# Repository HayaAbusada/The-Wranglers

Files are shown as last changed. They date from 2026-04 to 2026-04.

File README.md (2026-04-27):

# The-Wranglers
Final Deliverables Repository containing all materials used to develop this project.

## CSCE 483: Student Pick Up System Contents

### Designs: code, schematics, data, data sheets, freeware software tools, etc.
- Low Fidelity Designs
- CAD Designs
- Camera Code
- Website Code
- Server Code
- Raspberry Pi Data Sheet
- Raspberry Pi Camera Data Sheet

### Reports: proposal, CDR, weekly reports, final report, and ALL presentations
- Proposal
- CDR
- Final Report
- Weekly Report #1
- Weekly Report #2
- Weekly Report #3
- Weekly Report #4
- Weekly Report #5
- Weekly Report #6
- Weekly Report #7
- Proposal Presentation
- CDR Presentation
- Final Presentation

### Audiovisual Media: close-up pictures and demo video
- Video Demo
- System Photos

### Individual Notebooks (Digital)
- Jack Uehlinger’s Notebook
- Jake Hewett’s Notebook
- Jayden Pearson’s Notebook
- Sara Vorhaben’s Notebook 
- Haya Abusada’s Notebook

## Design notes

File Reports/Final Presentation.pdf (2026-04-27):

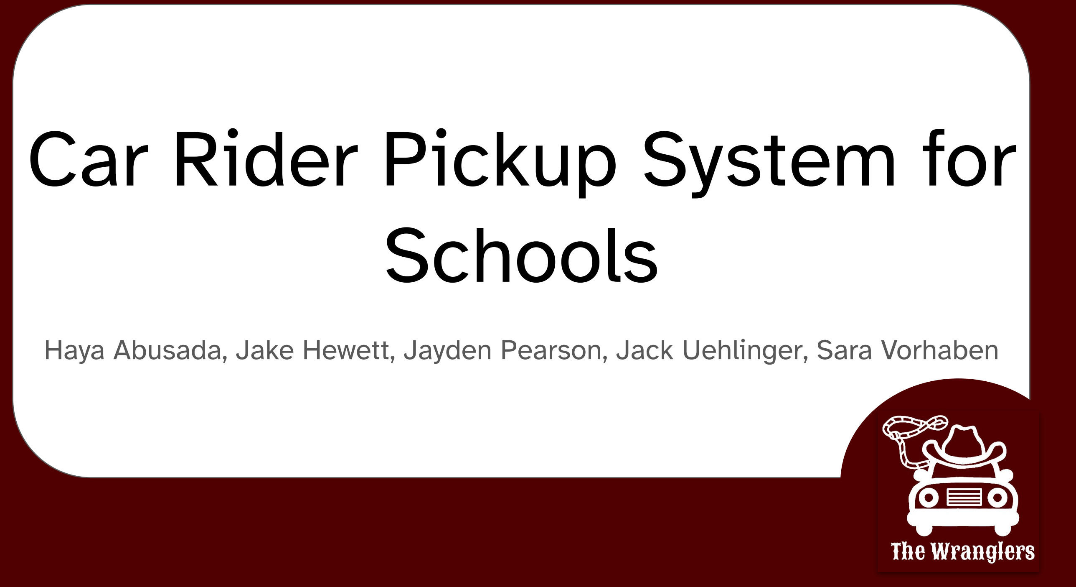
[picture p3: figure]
Car Rider Pickup System for Schools

# Haya Abusada, Jake Hewett, Jayden Pearson, Jack Uehlinger, Sara Vorhaben

# Problem Background

- Over 70% of students are now picked up via car, creating massive congestion.
- Parents wait up to 1 hour, with lines often forming 1-2 hours before dismissal.
- Queues spill onto local highways, causing traffic backups and increasing accident risks.
- Inclement weather increases delays as bus and bike riders often switch to the car line.

## - The manual process requires 5-10 staff members daily, diverting them from educational

duties.

# Problem - Needs Statement

## School pickup via the car rider line has been increasing in the US over the years leading to an increase in line length and pickup time. Now, over 70% of students are

picked up from school via the car rider line. Car rider lines have become congested,

posing a safety issue for both the students and other drivers. With more students attending school, car rider lines have become too slow and cause parents to wait up to over an hour in line leading to frustration. Some studies show that the car rider pick-up line starts to form 1-2 hours before school actually gets out, which leads to traffic backing up local highways and streets, and even frequent accidents. Inclement weather further slows the line, as students who ride the bus or bike to school will often

be picked up by their parents in the car rider line to avoid the weather. Additionally, 5-10

## staff members are required to set up and run the pickup process, diverting their time away from the education of students. An automated system is needed to streamline the

pick-up process to decrease delays and safety issues.

# Goal and Objectives

## Goal

The goal of this project is to design and prototype a system that will help automate the car rider pick up process at schools. The system is built to reduce the amount of time necessary to pick up students from school.

## Objectives

- The system will allow parents to update their information (license plate numbers, approved adults for pickup, car rider schedules) via a website with approval from a staff member of the school.
- The system will read the marker on the car (license plate, QR code, nametag) as it enters the pickup line and send the information to a server.
- The server will identify the parent and child associated with the car marker, and update a display at the entrance of the pickup line to direct the car to the proper station.
- The laptop at the front of the school is updated to inform the students and staff which child is being picked up, and which zone to go to.

# Goal and Objectives - Requirements

# Marketing Requirements

1. Make the pickup process faster for parents 2. The system should be easily updated 3. The system should be low cost 4. The system should be easy to use/install 5. Information must be validated if updated or inserted 6. Student safety should be ensured (information, physical, etc.) 7. The system should be reliable

# Goal and Objectives - Requirements

Marketing Requirements | Engineering Requirements | How Requirement was met
1 | Pickup time should be reduced by 30% per 100 kids. The time from the car entering the view of the camera to information being displayed should be no more than 5 seconds. | display updates <1 second
4 | 7 inch (diagonal) display screen to give station and process instructions clearly. | See Setup
1, 6 | Per Texas Family Code, ensure that students are referred to authorized parents 100% of the time. | Scanned QR code only works for approved users
6 | Private Information stored in the database should be encrypted using 128 bit encryption. | Database automatically encrypts
1,6,7 | Should correctly identify/assign parents to kids 100% of the time. | See Full System Test
3 | The costs for developing the system should not exceed $300. | See Budget
2,4,5 | The system should allow parents to submit a request to the school to update information and the school should receive the request all within 1 minute. | Aproval requests can be seen in system in <1 second

# Goal and Objectives - Requirements

Marketing Requirements | Engineering Requirements | How Requirement was met
4 | The system should have a modular design such that failed components can be replaced by a technician in under 15 minutes. | System designed so each system component could easily be replaced if broken
7 | The software will comply with the Digital Millennium Copyright Act. | No code was copied from existing sites
2,4,5,6 | Staff should be able to access databases with provided credentials and view all parent to children links. | See staff portal
1 | Minimum 40inch (diagonal) display screen to give station and process instructions clearly inside in the pickup . | See System Setup: display Student Pickup screen inside on TV/Smartboard in classroom
4,7 | The system should be mounted correctly on a tripod to ensure stability and prevent hazards. | See Car Entrance Model Setup.

# Design Constraints and Feasibility

Technical and Temporal Constraints

- Maximum of 5 seconds from image capture to display update
- Identification accuracy must be 100% to ensure safety and efficiency
- Connection between the system parts must be reliable

Physical and Environmental

- Needs to withstand outdoor elements (wind and rain)
- Needs to be portable and stable with modular parts, mounting, and power supply to reduce system downtime and speed up repair and maintenance

Economic

- Must cost $250 or less, necessitating cost-effective components

Feasibility

- Core technology, such as Python image processing and Wi-Fi, is well documented and achievable
- Main challenge will be creating a fast and efficient system within our budget

# Design Alternatives and Rationale

Solution | Pros | Cons
Manual Pickup App (PikMyKid) | Easy to implement; low cost; reduces paperwork | Requires staff queue management; no automated vehicle identification
Integrated Dismissal System (Beeline) | Improves communication; integrates with school systems | Requires training and infrastructure; still staff-monitored
Geofencing (Car-Pool App) | Real-time arrival alerts; reduced manual check-ins | Dependent on GPS accuracy, mobile devices, and connectivity
GPS Check-In (IschoolRide) | Keeps students inside until arrival; reduces idle staging | Relies on parent app usage and accurate GPS; staff verification will still be needed

All alternatives improve organization but still rely on staff actions, limiting full automation.

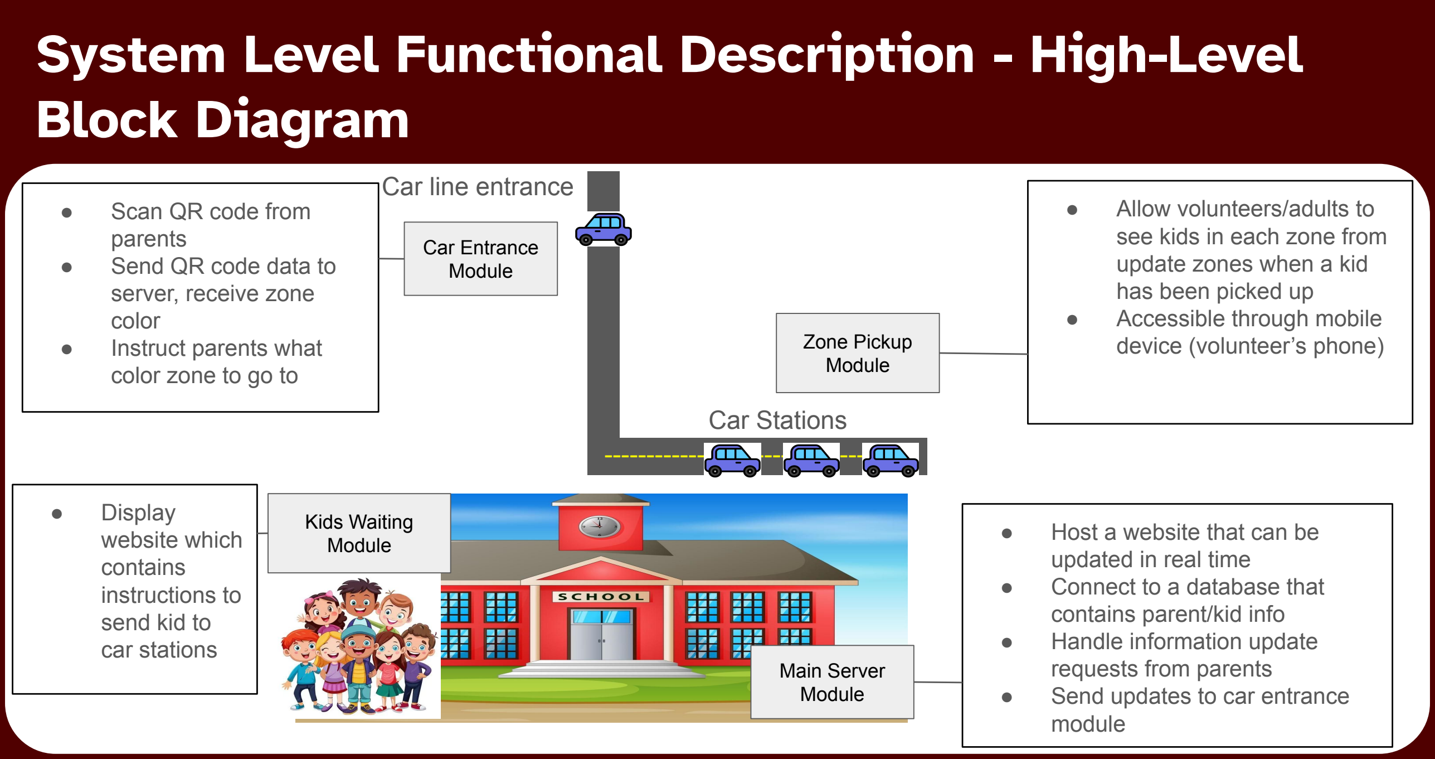
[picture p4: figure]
Block Diagram; Car line entrance; Car Stations; Car Entrance Module; Main Server Module; Kids Waiting Module; Zone Pickup Module; ● Scan QR code from parents ● Send QR code data to server, receive zone color ● Instruct parents what color zone to go to; ● Display website which contains instructions to send kid to car stations; ● Allow volunteers/adults to see kids in each zone from update zones when a kid has been picked up ● Accessible through mobile device (volunteer’s phone)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

# System Level Functional Description - High-Level

# System Component - Car Entrance Module

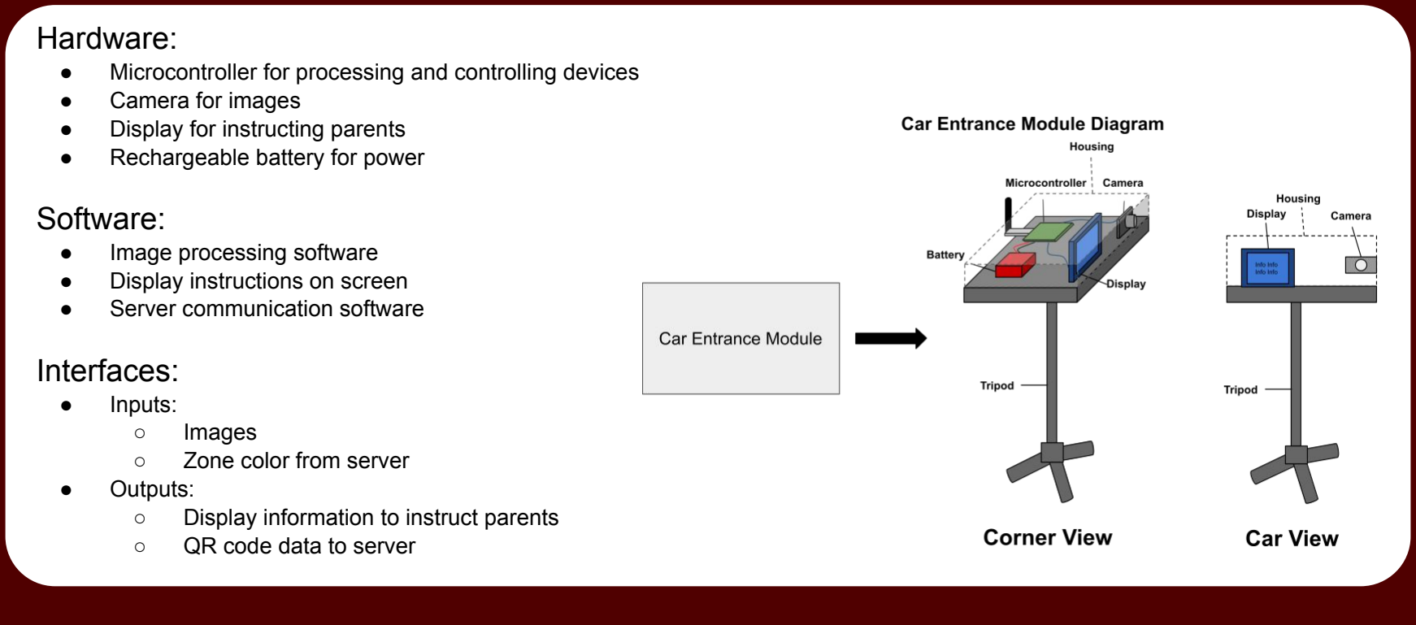
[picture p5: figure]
Hardware:; ● Camera for images ● Display for instructing parents ● Rechargeable battery for power; Software:; ● Image processing software ● Display instructions on screen ● Server communication software; Interfaces:; ● Inputs: ○ Images ○ Zone color from server ● Outputs:; ○ QR code data to server

- Microcontroller for processing and controlling devices
- Display information to instruct parents

System Component - Car Entrance Module cont.

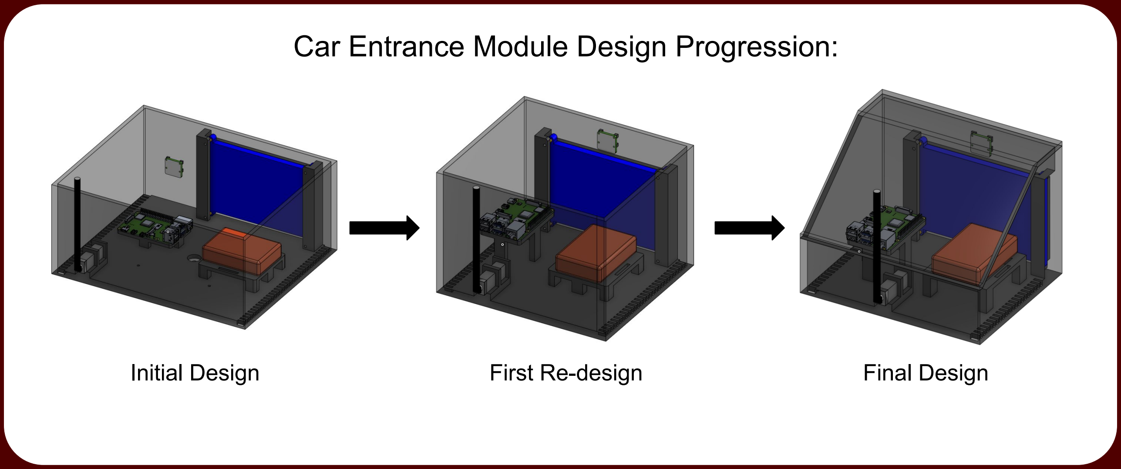
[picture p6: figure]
Car Entrance Module Design Progression:

Initial Design | First Re-design | Final Design

# System Component - Zone Pickup Module

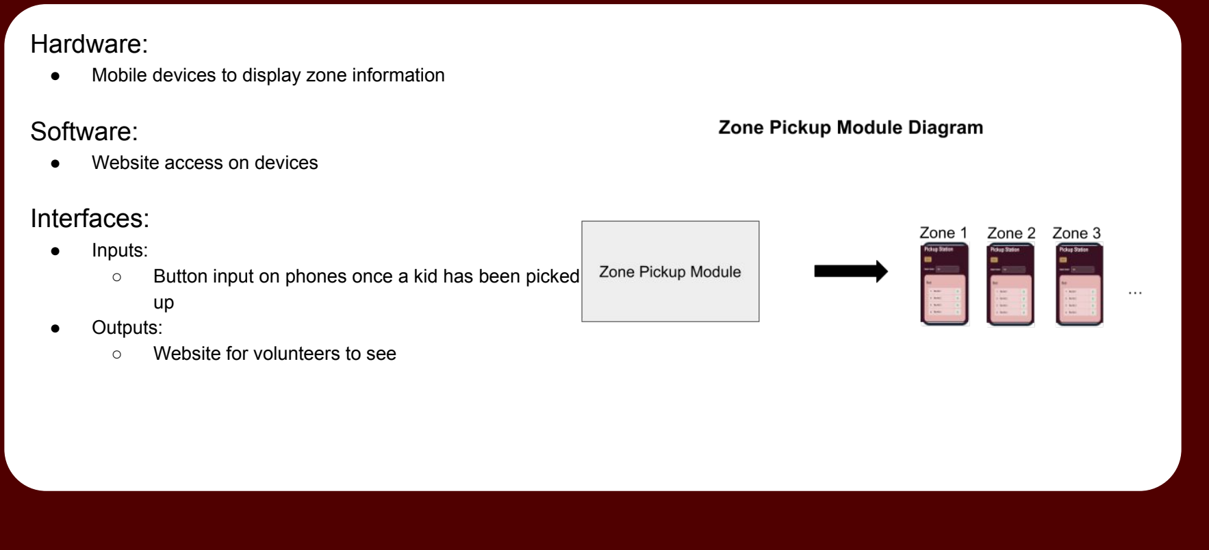
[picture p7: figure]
Hardware:; Software:; ● Website access on devices; Interfaces:; ● Inputs:; up ● Outputs: ○ Website for volunteers to see

- Mobile devices to display zone information
- Button input on phones once a kid has been picked

# System Component - Main Server Module

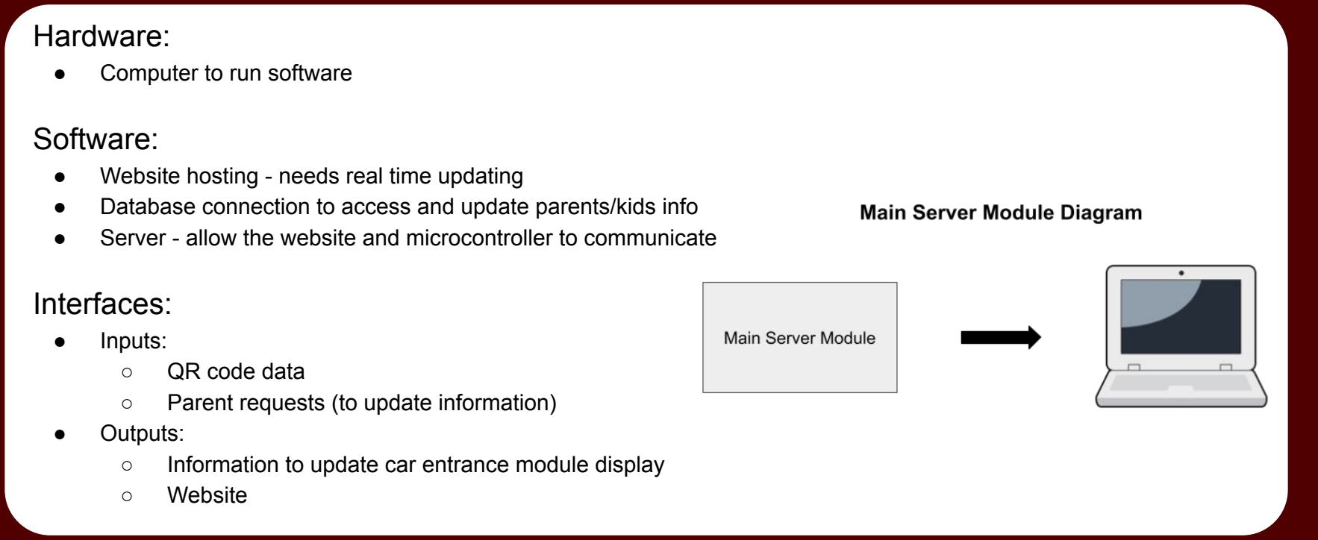
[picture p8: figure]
Hardware:; ● Computer to run software; Software:; Interfaces:; ● Inputs: ○ QR code data; ● Outputs:; ○ Website

- Website hosting - needs real time updating
- Database connection to access and update parents/kids info
- Server - allow the website and microcontroller to communicate
- Parent requests (to update information)
- Information to update car entrance module display

# System Component - Kids Waiting Module

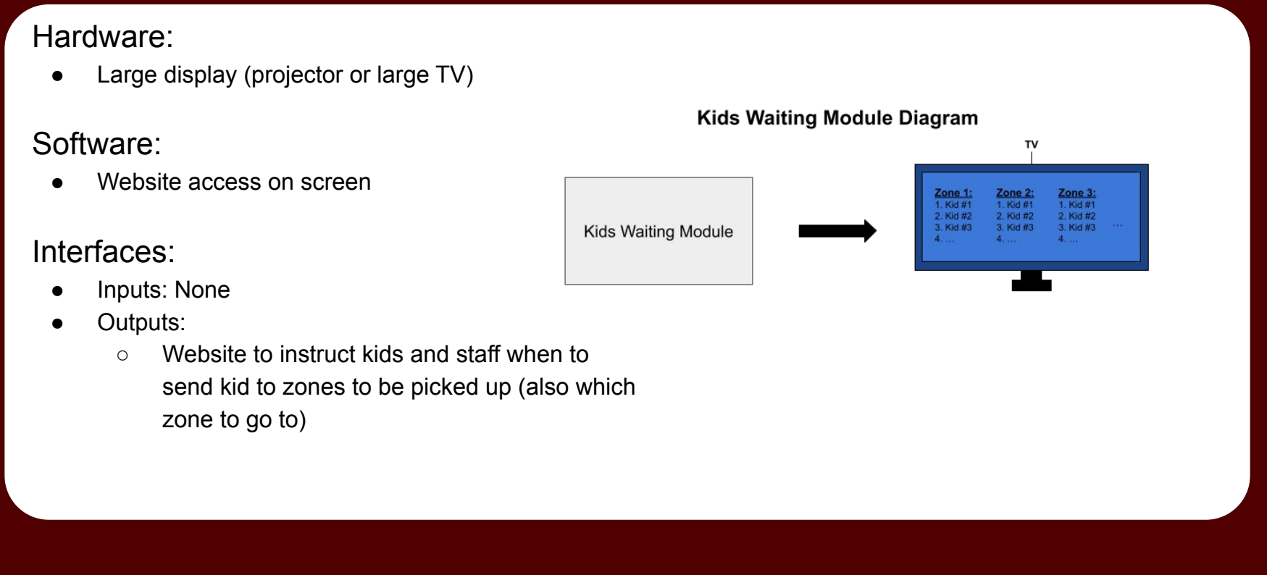
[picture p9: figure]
Hardware:; ● Large display (projector or large TV); Software:; ● Website access on screen; Interfaces:; ● Inputs: None ● Outputs:; zone to go to)

- Website to instruct kids and staff when to send kid to zones to be picked up (also which

# Budget Breakdown

Module | Component | Description | Qty | Unit Cost ($) | Total Cost ($)
Car Entrance | Tripod | Tripod to support car entrance module housing. | 1 | $22 | $22
Car Entrance | Raspberry Pi | Microcontrollers to control car entrance and zone pickup modules. | 1 | $75 | $75*
Car Entrance | Raspberry Pi Camera | Camera to use license plate recognition of cars. | 1 | $55 | $55*
Car Entrance | 10000mAh Rechargeable Battery | Batteries to give sufficient power to the car entrance and zone pickup module. | 1 | $40 | $40
Car Entrance | 7-inch display | Display to inform the parent of the car what zone to go to, and verify we have matched their car with their kid. | 1 | $38 | $38*
Car Entrance | HDMI Cord | HDMI cord to connect the microcontroller to the display. | 1 | $4 | $4
Car Entrance | 3D printing | 3D printed housings for car entrance and zone pickup modules. | | | $36.55**
Car Entrance | Mounting Screws | Screws to securely mount components to housings. | ~40 | $8 (600pcs) | $8
Total* (not including components provided) | | | | | $74
Total | | | | | $278.55

Budget Breakdown - cont.

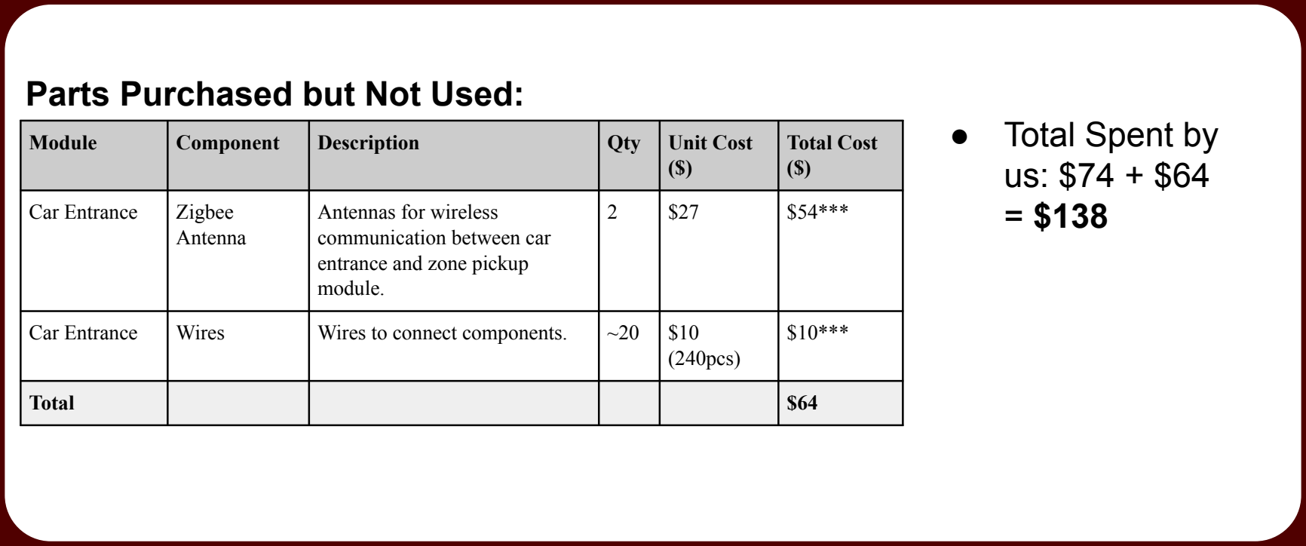
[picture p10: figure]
Module; Component; Description; Qty; Unit Cost ($); Total Cost ($); Car Entrance; Wires; Wires to connect components.; $10 (240pcs); Total; Parts Purchased but Not Used:; ● Total Spent by us: $74 + $64 = $138

Car Entrance | Zigbee Antenna | Antennas for wireless communication between car entrance and zone pickup module. | 2 | $27 | $54***

# Evidence of Effective Teaming

Defined Roles and Responsibilities

Each team member is responsible for a specific subsystem:

- Haya Abusada – Frontend development and system integration
- Sara Vorhaben – Backend development and authentication
- Jake Hewett – Database architecture and administrative interface
- Jack Uehlinger – Hardware and camera integration
- Jayden Pearson – Mechanical design and enclosure development

This ensures clear ownership of tasks and efficient development.

Collaboration and Communication

The team maintains strong coordination through:

- Weekly team meetings to review progress and address issues
- GitHub for version control and collaborative development
- Discord and Text for daily communication and troubleshooting
- Google Drive for shared documentation and reports

Screenshot of Github Repo

# Evidence of Effective Teaming - Gantt Chart

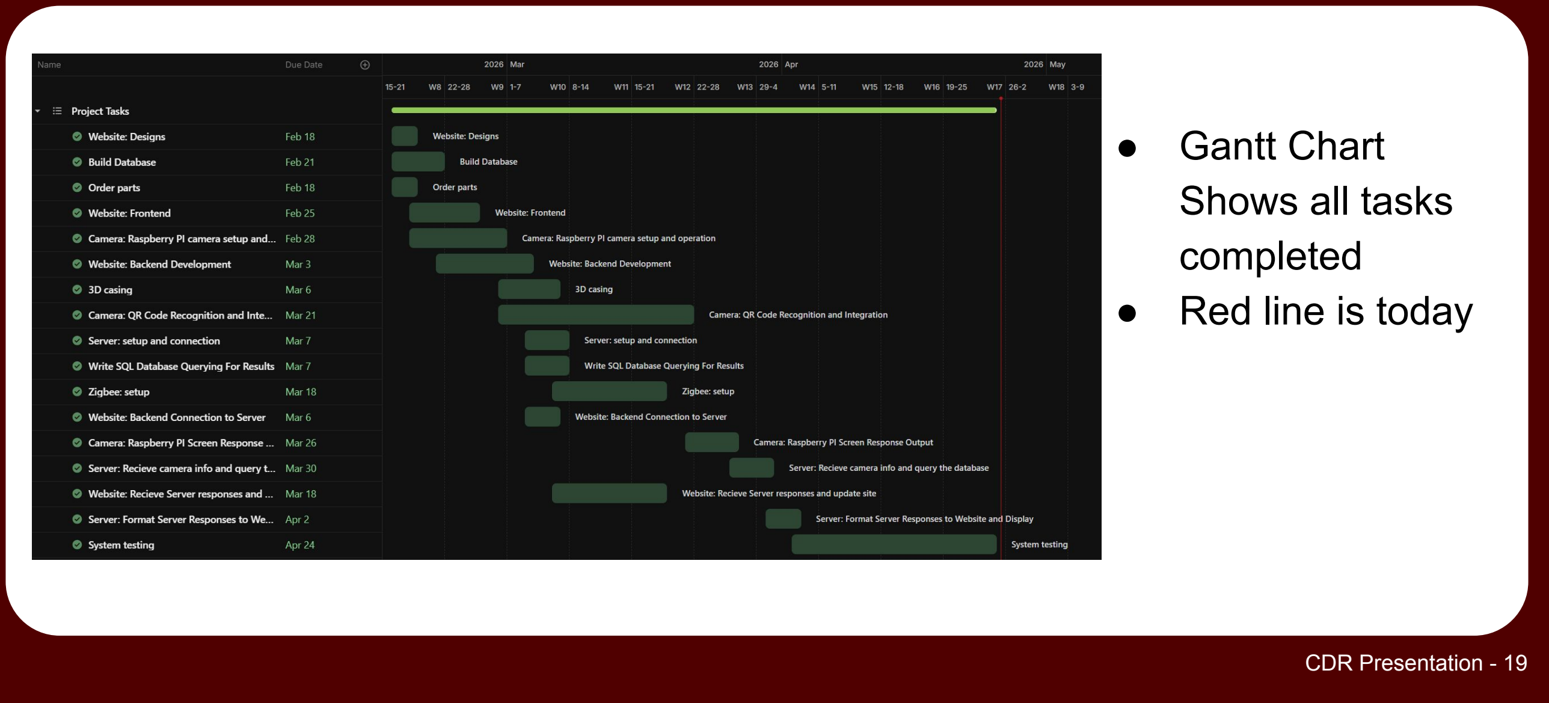
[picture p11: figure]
● Gantt Chart Shows all tasks completed ● Red line is today; CDR Presentation - 19

# Environmental, Health, and Safety Concerns

### Environmental Impact

### - Minimal hardware footprint (primarily existing devices like monitors and Raspberry Pi) - Reduced vehicle idling time → lowers emissions during pickup - Digital system reduces paper usage (no printed pickup lists)

### Health Considerations

### - Contactless QR code system reduces physical interaction - Minimizes crowding and improves traffic flow for safer pickup conditions

### Safety Considerations

### - Clear, color-coded display reduces confusion for drivers - Organized station system prevents congestion and accidents

# Social, Political, and Ethical Concerns

- Social Impact - Improves efficiency and reduces wait times for families - Enhances safety for students during pickup - Accessible interface designed for non-technical users - Ethical Considerations - Protection of personal data (student and parent information) - Use of secure authentication (Google OAuth) - Controlled access to staff-only features - Political / Regulatory Considerations - Must comply with school policies and student privacy regulations (e.g., FERPA) - Requires proper authorization for data collection and usage - Deployment depends on school/district approval and infrastructure

# Manufacturability, sustainability, and economics

### Manufacturability - Software-based system → easily deployable and scalable - Uses widely available hardware (monitors, laptops, Raspberry Pi) - No specialized manufacturing required

### Sustainability - Reduces fuel consumption through optimized pickup flow - Digital-first approach minimizes material waste - Scalable system reduces need for additional infrastructure

### Economic Considerations - Low implementation cost (open-source tools, cloud services) - Minimal hardware investment - Reduces labor inefficiencies and operational costs for schools

# Our Final Product Video

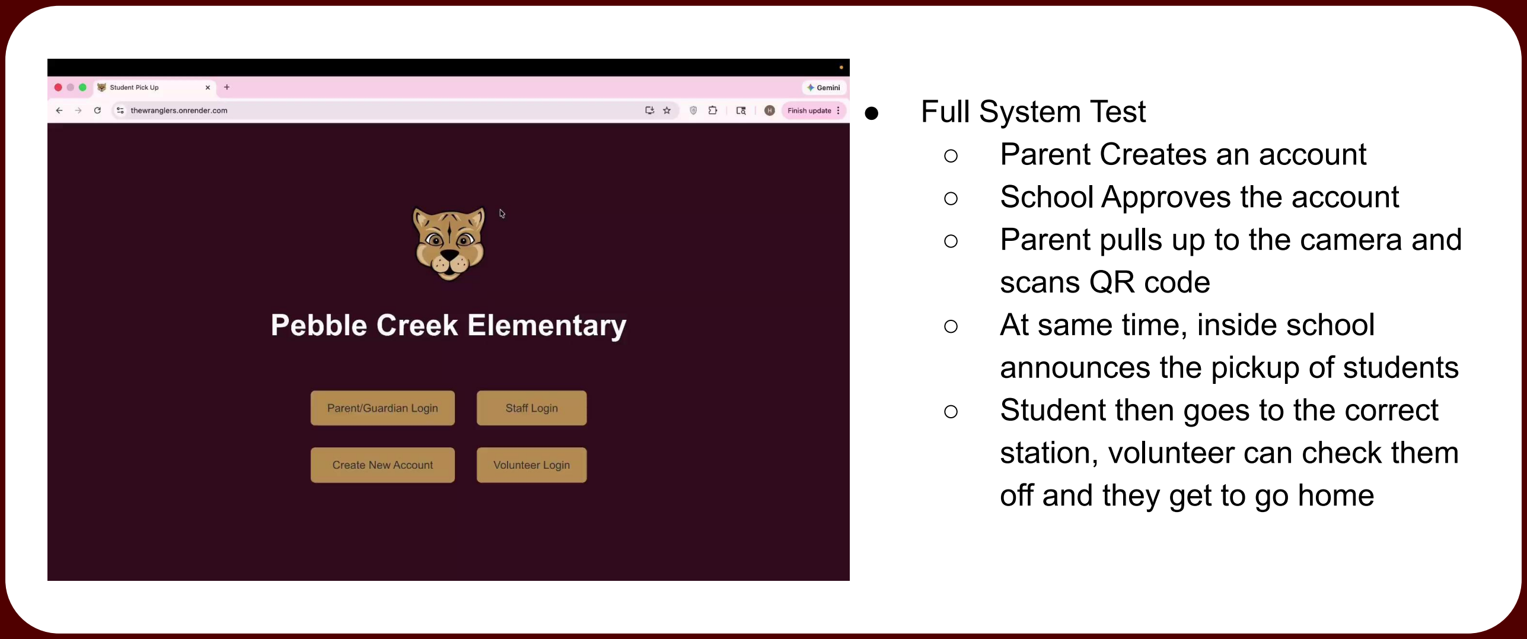
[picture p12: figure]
● Full System Test ○ Parent Creates an account ○ School Approves the account ○ Parent pulls up to the camera and scans QR code ○ At same time, inside school announces the pickup of students ○ Student then goes to the correct station, volunteer can check them off and they get to go home; video

# Testing and Results

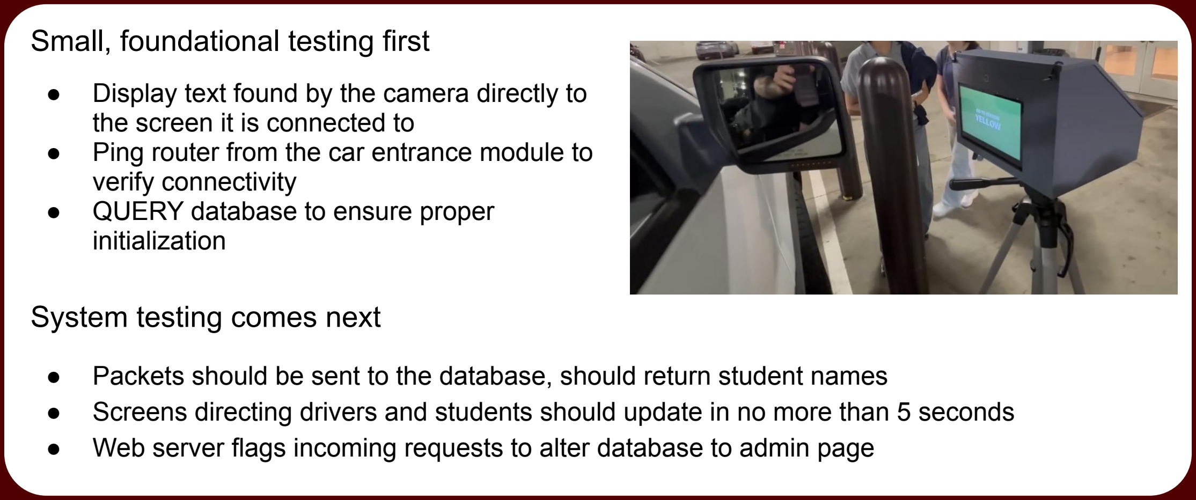
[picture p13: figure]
Small, foundational testing first; the screen it is connected to; verify connectivity ● QUERY database to ensure proper initialization; System testing comes next

## - Display text found by the camera directly to

## - Ping router from the car entrance module to

## - Packets should be sent to the database, should return student names - Screens directing drivers and students should update in no more than 5 seconds - Web server flags incoming requests to alter database to admin page

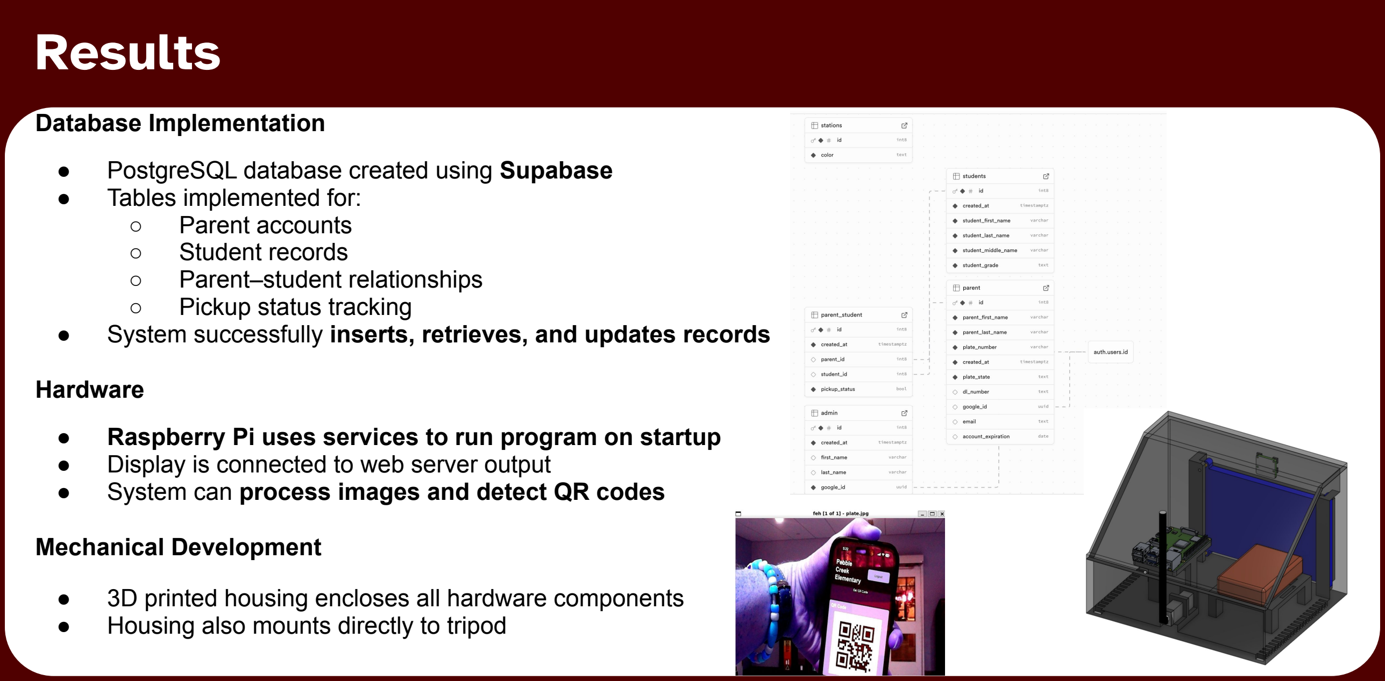
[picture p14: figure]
Results; Database Implementation; ● Tables implemented for: ○ Parent accounts ○ Student records ○ Parent–student relationships ○ Pickup status tracking; Hardware; Mechanical Development

- PostgreSQL database created using Supabase
- System successfully inserts, retrieves, and updates records
- Raspberry Pi uses services to run program on startup
- Display is connected to web server output
- System can process images and detect QR codes
- 3D printed housing encloses all hardware components
- Housing also mounts directly to tripod

# Results

Some of the Results for Testing Can be seen below:

Test | Time To complete
Time for Someone with no experience to create and account and add a child | 44 Seconds
Time for Full system pickup (drive up, scan QR Code, Pull Forward) | 1 minute and 3 seconds for 2 cars
Time to approve student | ~2 seconds
Time to Generate Approved QR Code | Less than 1 second
Battery life of the Car Entrance Module | Greater than 2.5 hours
Time To Display Successful Result after QR Scan | ~1 second

# Limitations

## Zigbee Antenna Integration Removed

## - Initial plan included Zigbee communication between modules - Incorrect hardware was ordered and could not be programmed in time - System was redesigned to operate without Zigbee

## License Plate Recognition Not Implemented

## - Tested but found to be unreliable - Performance varied significantly with lighting conditions, camera angle, and distance - Risk of incorrect identification was too high for real-world use

## Dependence on Network Connectivity

## - System requires stable internet connection for real-time updates - Performance may degrade with poor connectivity

# Future Improvements

Improved Identification Methods

- Integrate more reliable computer vision models for license plate recognition
- Combine QR codes with automated recognition for redundancy

Real-Time Communication

- Replace polling with WebSockets or MQTT for instant updates
- Improve system responsiveness and scalability

Scalability and Deployment

- Support multiple schools or larger campuses
- Add admin tools for managing stations and users dynamically

External Power Button

- Current setup requires staff to lift lid and plug in battery
- An external power switch would improve usability

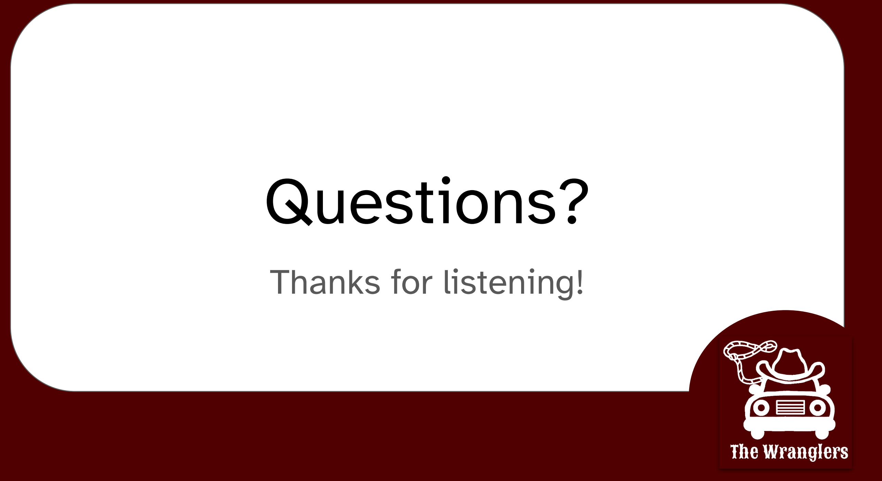
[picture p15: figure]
Questions?; Thanks for listening!

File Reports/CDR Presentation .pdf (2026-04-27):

Car Rider Pickup System for Schools

# Haya Abusada, Jake Hewett, Jayden Pearson, Jack Uehlinger, Sara Vorhaben

# Problem Background

- Over 70% of students are now picked up via car, creating massive congestion.
- Parents wait up to 1 hour, with lines often forming 1-2 hours before dismissal.
- Queues spill onto local highways, causing traffic backups and increasing accident risks.
- Inclement weather increases delays as bus and bike riders often switch to the car line.

## - The manual process requires 5-10 staff members daily, diverting them from educational

duties.

CDR Presentation - 2

# Problem - Needs Statement

## School pickup via the car rider line has been increasing in the US over the years leading to an increase in line length and pickup time. Now, over 70% of students are

picked up from school via the car rider line. Car rider lines have become congested,

posing a safety issue for both the students and other drivers. With more students attending school, car rider lines have become too slow and cause parents to wait up to over an hour in line leading to frustration. Some studies show that the car rider pick-up line starts to form 1-2 hours before school actually gets out, which leads to traffic backing up local highways and streets, and even frequent accidents. Inclement weather further slows the line, as students who ride the bus or bike to school will often

be picked up by their parents in the car rider line to avoid the weather. Additionally, 5-10

## staff members are required to set up and run the pickup process, diverting their time away from the education of students. An automated system is needed to streamline the

pick-up process to decrease delays and safety issues.

# Goal and Objectives

### Goal

The goal of this project is to design and prototype a system that will help automate the car rider pick up process at schools. The system is built to reduce the amount of time necessary to pick up students from school.

### Objectives

- The system will allow parents to update their information (license plate numbers, approved adults for pickup, car rider schedules) via a website with approval from a staff member of the school.
- The system will read the marker on the car (license plate, QR code, nametag) as it enters the pickup line and send the information to a server.
- The server will identify the parent and child associated with the car marker, and update a display at the entrance of the pickup line to direct the car to the proper station.
- The laptop at the front of the school is updated to inform the students and staff which child is being picked up, and which zone to go to.

# Goal and Objectives - Requirements

# Marketing Requirements

1. Make the pickup process faster for parents 2. The system should be easily updated 3. The system should be low cost 4. The system should be easy to use/install 5. Information must be validated if updated or inserted 6. Student safety should be ensured (information, physical, etc.) 7. The system should be reliable

# Goal and Objectives - Requirements

Marketing Requirements | Engineering Requirements
1 | Pickup time should be reduced by 30% per 100 kids. The time from the car entering the view of the camera to information being displayed should be no more than 5 seconds.
4 | 7 inch (diagonal) display screen to give station and process instructions clearly.
1, 6 | Per Texas Family Code, ensure that students are referred to authorized parents 100% of the time.
6 | Private Information stored in the database should be encrypted using 128 bit encryption.
7 | Should have a stable connection from within 1 kilometer, stable power to all components.
1,6,7 | Should correctly identify/assign parents to kids 100% of the time.
3 | The costs for developing the system should not exceed $300.
2,4,5 | The system should allow parents to submit a request to the school to update information and the school should receive the request all within 1 minute.

# Goal and Objectives - Requirements

Marketing Requirements | Engineering Requirements
4 | The system should have a modular design such that failed components can be replaced by a technician in under 15 minutes.
4,7 | The system should be mounted correctly on a tripod to ensure stability and prevent hazards. Sandbag/Weights of at least 1 pound to keep it grounded.
7 | The software will comply with the Digital Millennium Copyright Act.
2,4,5,6 | Staff should be able to access databases with provided credentials and view all parent to children links.
4,7 | The system should be able to withstand 20mph wind.
1 | Minimum 40inch (diagonal) display screen to give station and process instructions clearly inside in the pickup .
4 | The system should have a modular design such that failed components can be replaced by a technician in under 15 minutes.
4,7 | The system should be mounted correctly on a tripod to ensure stability and prevent hazards. Sandbag/Weights of at least 1 pound to keep it grounded.

# Design Constraints and Feasibility

Technical and Temporal Constraints

- Maximum of 5 seconds from image capture to display update
- Identification accuracy must be 100% to ensure safety and efficiency
- Connection between the system parts must be reliable

Physical and Environmental

- Needs to withstand outdoor elements (wind and rain)
- Needs to be portable and stable with modular parts, mounting, and power supply to reduce system downtime and speed up repair and maintenance

Economic

- Must cost $250 or less, necessitating cost-effective components

Feasibility

- Core technology, such as Python image processing and Wi-Fi, is well documented and achievable
- Main challenge will be creating a fast and efficient system within our budget

# Evaluation of alternative solutions and Rationale

Solution | Pros | Cons
Manual Pickup App (PikMyKid) | Easy to implement; low cost; reduces paperwork | Requires staff queue management; no automated vehicle identification
Integrated Dismissal System (Beeline) | Improves communication; integrates with school systems | Requires training and infrastructure; still staff-monitored
Geofencing (Car-Pool App) | Real-time arrival alerts; reduced manual check-ins | Dependent on GPS accuracy, mobile devices, and connectivity
GPS Check-In (IschoolRide) | Keeps students inside until arrival; reduces idle staging | Relies on parent app usage and accurate GPS; staff verification will still be needed
QR Codes (Kids Pick Up App) | Simple, affordable; no cellular service required | Requires staff scanning; affected by glare, weather, and visibility

All alternatives improve organization but still rely on staff actions or parent interaction, limiting full automation.

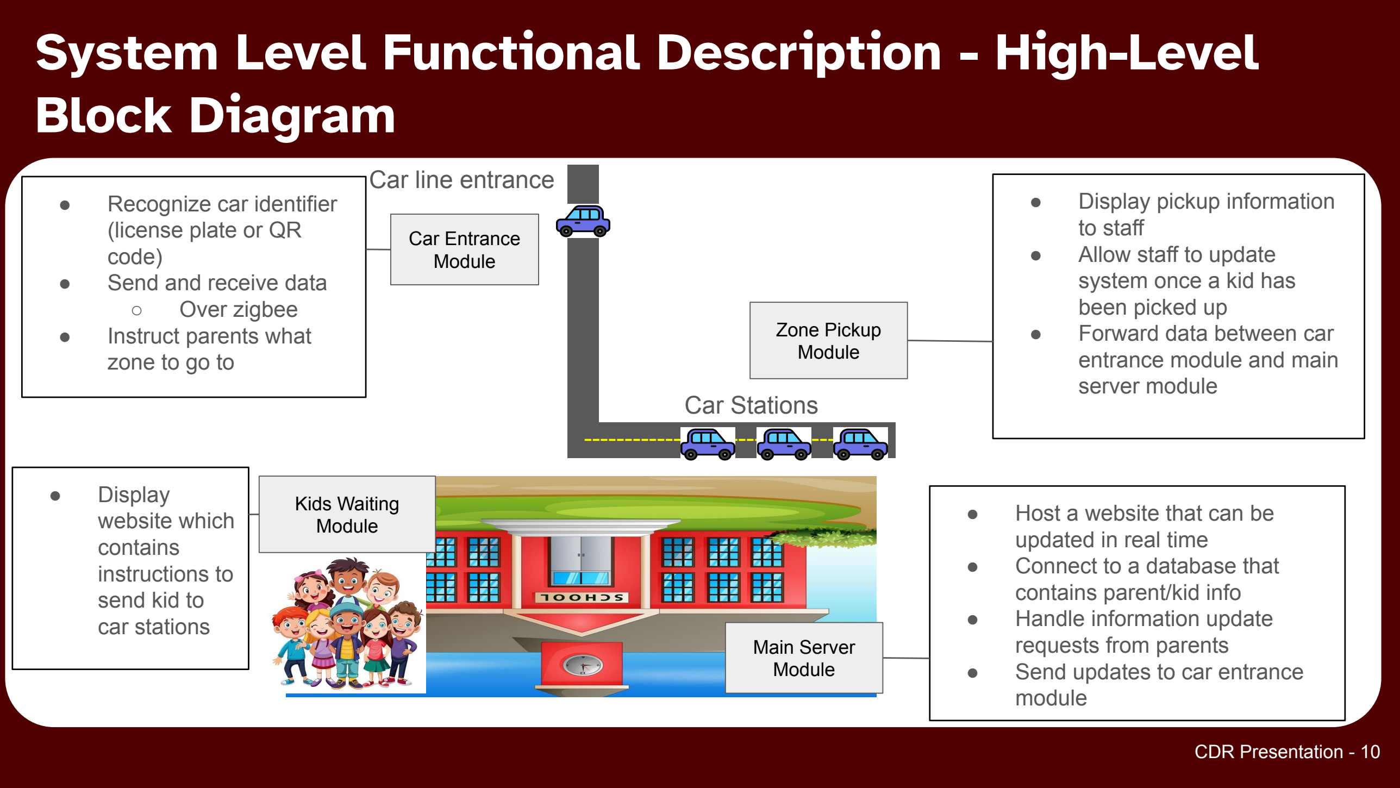
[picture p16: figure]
Block Diagram; Car line entrance; Car Stations; Car Entrance Module; Main Server Module; Kids Waiting Module; Zone Pickup Module; ● Recognize car identifier (license plate or QR code) ● Send and receive data ○ Over zigbee ● Instruct parents what zone to go to; ● Display website which contains instructions to send kid to car stations; ● Display pickup information to staff ● Allow staff to update system once a kid has been picked up ● Forward data between car entrance module and main server module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

# System Level Functional Description - High-Level

# System Component - Car Entrance Module

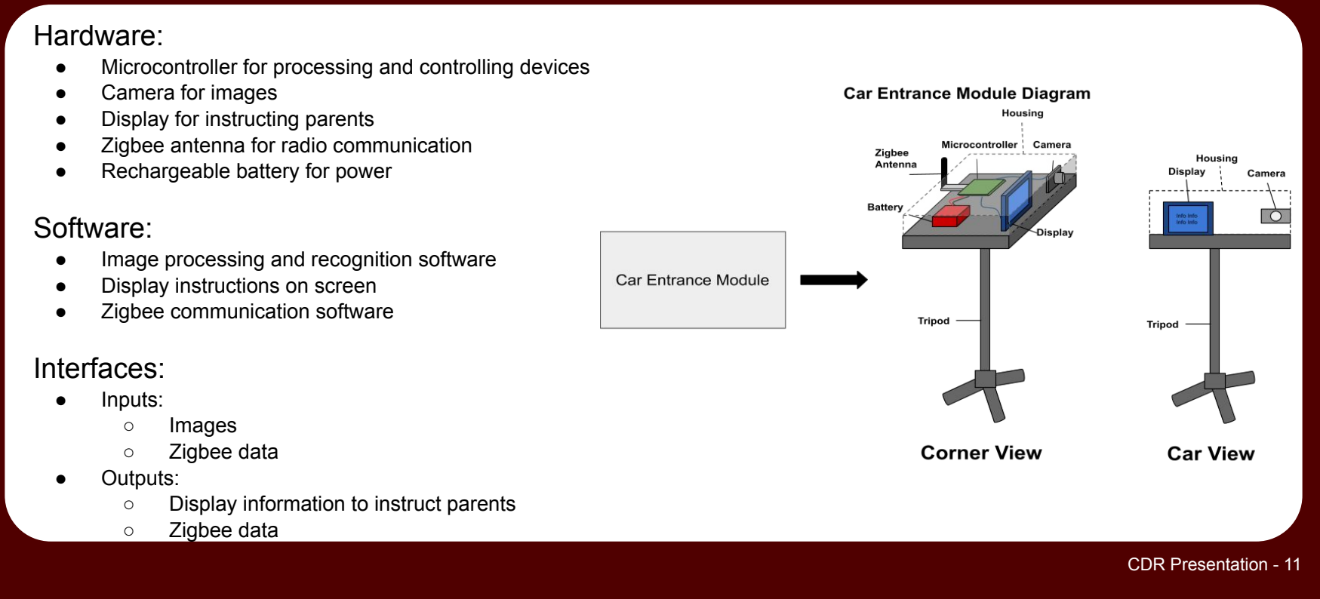
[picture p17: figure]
Hardware:; ● Camera for images ● Display for instructing parents; ● Rechargeable battery for power; Software:; ● Display instructions on screen ● Zigbee communication software; Interfaces:; ● Inputs: ○ Images ○ Zigbee data ● Outputs:; ○ Zigbee data

- Microcontroller for processing and controlling devices
- Zigbee antenna for radio communication
- Image processing and recognition software
- Display information to instruct parents

# System Component - Zone Pickup Module

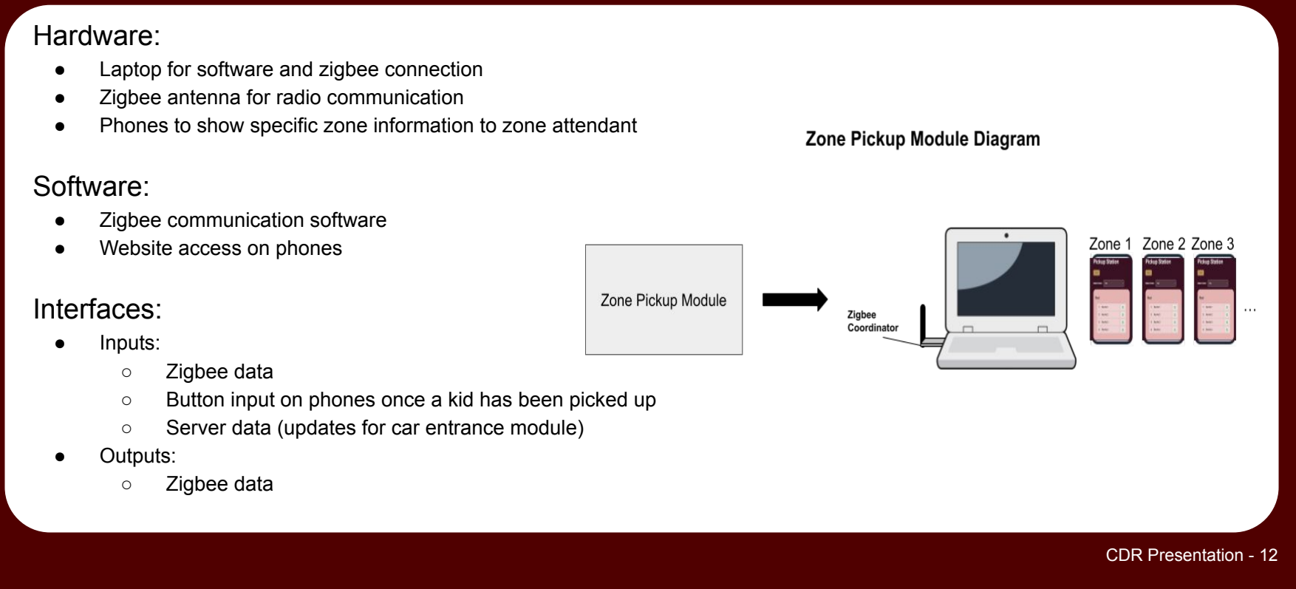
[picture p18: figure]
Hardware:; Software:; ● Zigbee communication software ● Website access on phones; Interfaces:; ● Inputs: ○ Zigbee data; ● Outputs: ○ Zigbee data

- Laptop for software and zigbee connection
- Zigbee antenna for radio communication
- Phones to show specific zone information to zone attendant
- Button input on phones once a kid has been picked up
- Server data (updates for car entrance module)

# System Component - Main Server Module

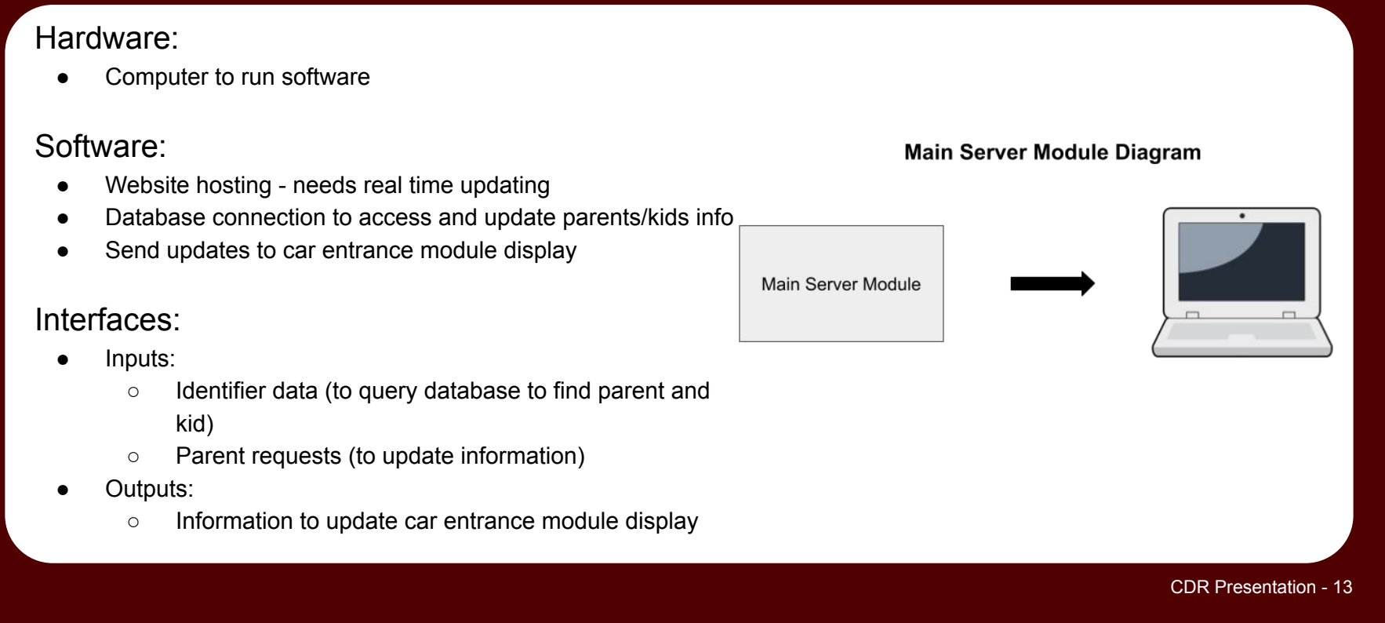
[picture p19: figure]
Hardware:; ● Computer to run software; Software:; Interfaces:; ● Inputs:; kid); ● Outputs:

- Website hosting - needs real time updating
- Database connection to access and update parents/kids info
- Send updates to car entrance module display
- Identifier data (to query database to find parent and
- Parent requests (to update information)
- Information to update car entrance module display

# System Component - Kids Waiting Module

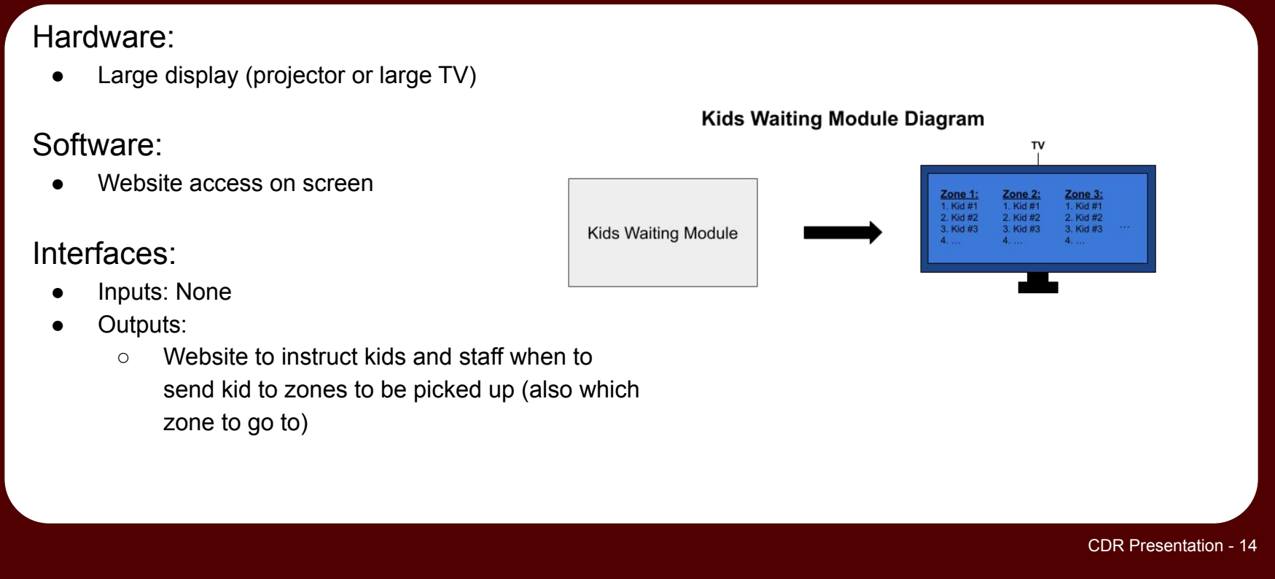
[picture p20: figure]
Hardware:; ● Large display (projector or large TV); Software:; ● Website access on screen; Interfaces:; ● Inputs: None ● Outputs:; zone to go to)

- Website to instruct kids and staff when to send kid to zones to be picked up (also which

# Design Validation and Testing - 1

## Small, foundational testing first

### - Verify connectivity to web server and database - Display text found by the camera directly to the screen it is connected to - Ping router from the car entrance module to verify connectivity - QUERY database to ensure proper initialization

## System testing comes next

### - Packets should be sent to the database, should return student names - Screens directing drivers and students should update in no more than 5 seconds - Web server flags incoming requests to alter database to admin page

# Design Validation and Testing - 2

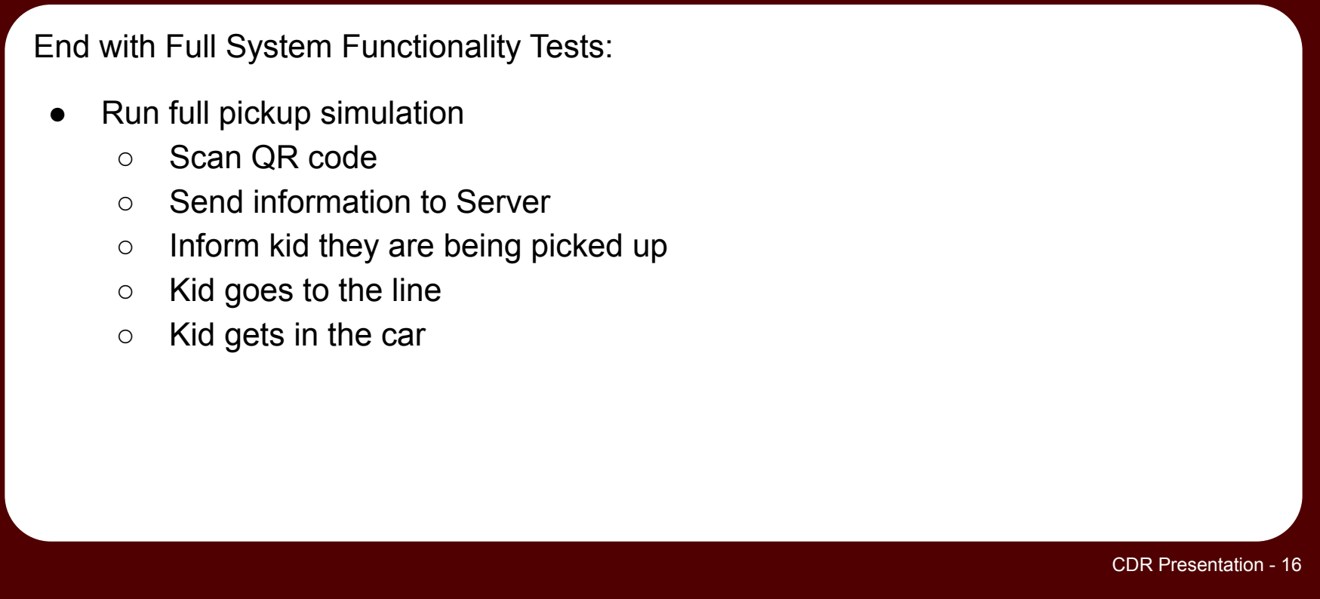
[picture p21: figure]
● Run full pickup simulation ○ Scan QR code ○ Send information to Server ○ Inform kid they are being picked up ○ Kid goes to the line ○ Kid gets in the car

## End with Full System Functionality Tests:

# Vision for Product Demonstration

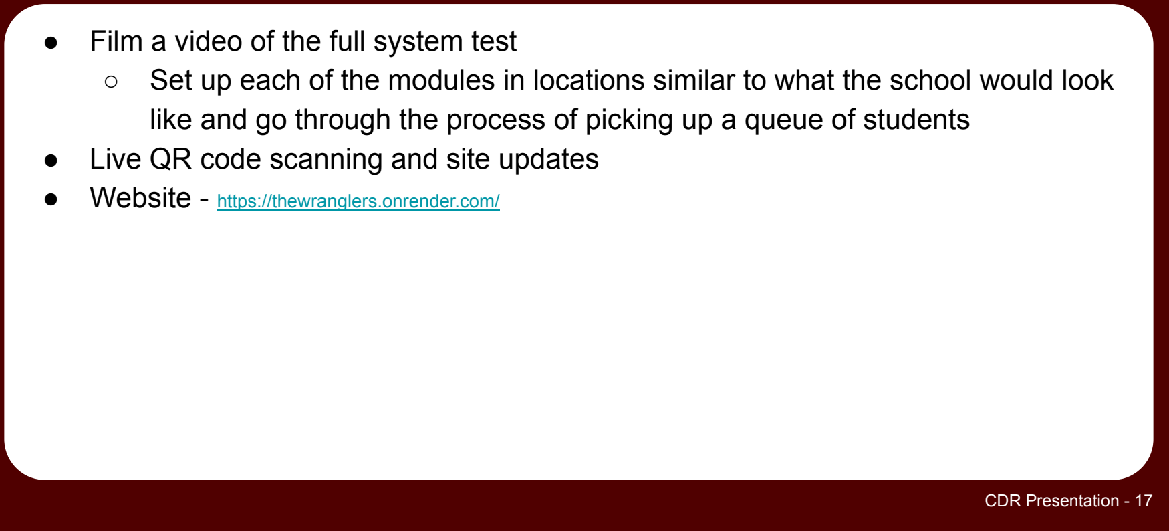
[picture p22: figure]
● Film a video of the full system test; ● Website - https://thewranglers.onrender.com/

## - Set up each of the modules in locations similar to what the school would look like and go through the process of picking up a queue of students - Live QR code scanning and site updates

# Evidence of Effective Teaming

Defined Roles and Responsibilities

Each team member is responsible for a specific subsystem:

- Haya Abusada – Frontend development and system integration
- Sara Vorhaben – Backend development and authentication
- Jake Hewett – Database architecture and administrative interface
- Jack Uehlinger – Hardware and camera integration
- Jayden Pearson – Mechanical design and enclosure development

This ensures clear ownership of tasks and efficient development.

Collaboration and Communication

The team maintains strong coordination through:

- Weekly team meetings to review progress and address issues
- GitHub for version control and collaborative development
- Discord for daily communication and troubleshooting
- Google Drive for shared documentation and reports

Screenshot of Github Repo

# Evidence of Effective Teaming - Gantt Chart

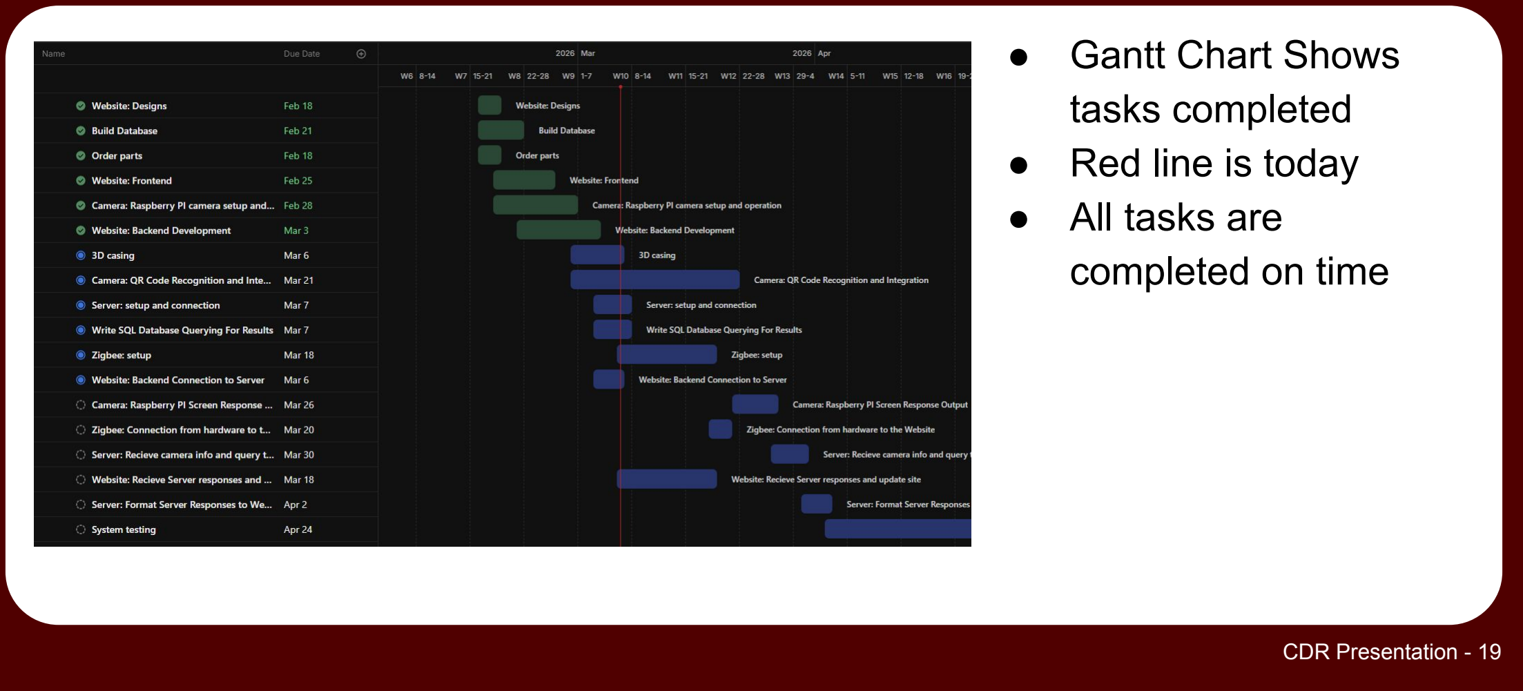
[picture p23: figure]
● Gantt Chart Shows tasks completed ● Red line is today ● All tasks are completed on time

# Preliminary Results

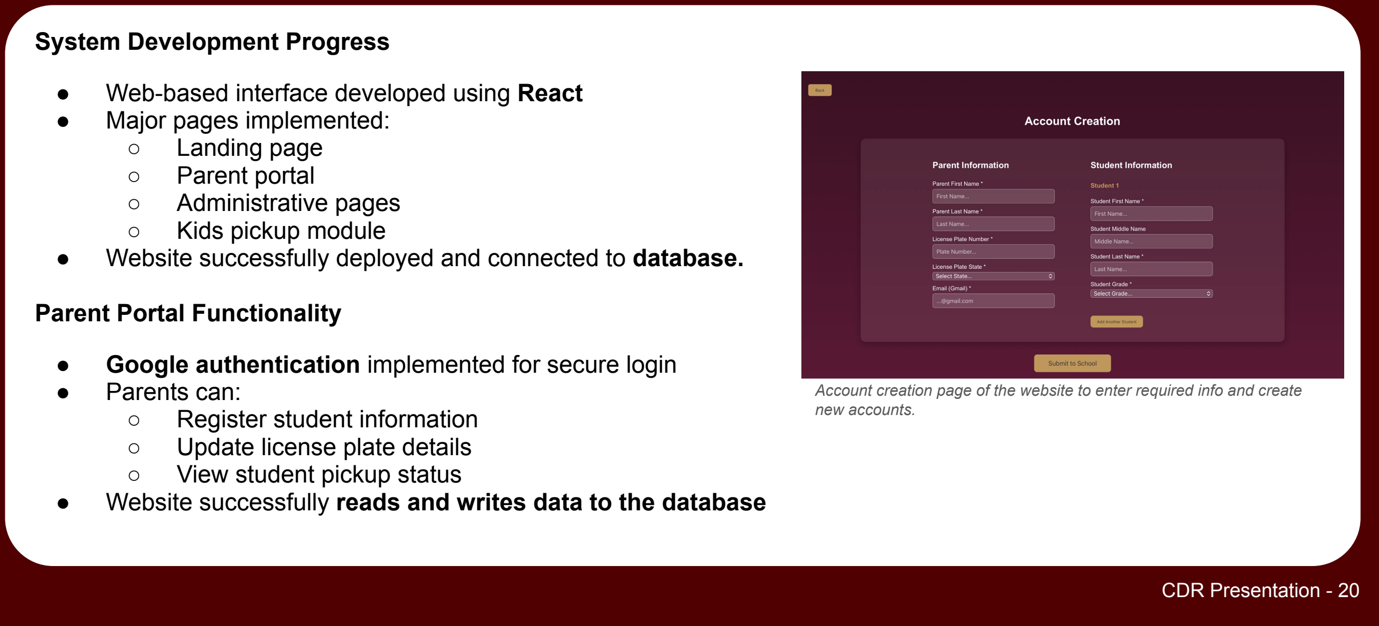
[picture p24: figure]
System Development Progress; ● Major pages implemented: ○ Landing page ○ Parent portal ○ Administrative pages ○ Kids pickup module; Parent Portal Functionality; ● Parents can: ○ Register student information ○ Update license plate details ○ View student pickup status; new accounts.

- Web-based interface developed using React
- Website successfully deployed and connected to database.
- Google authentication implemented for secure login
- Website successfully reads and writes data to the database

Account creation page of the website to enter required info and create

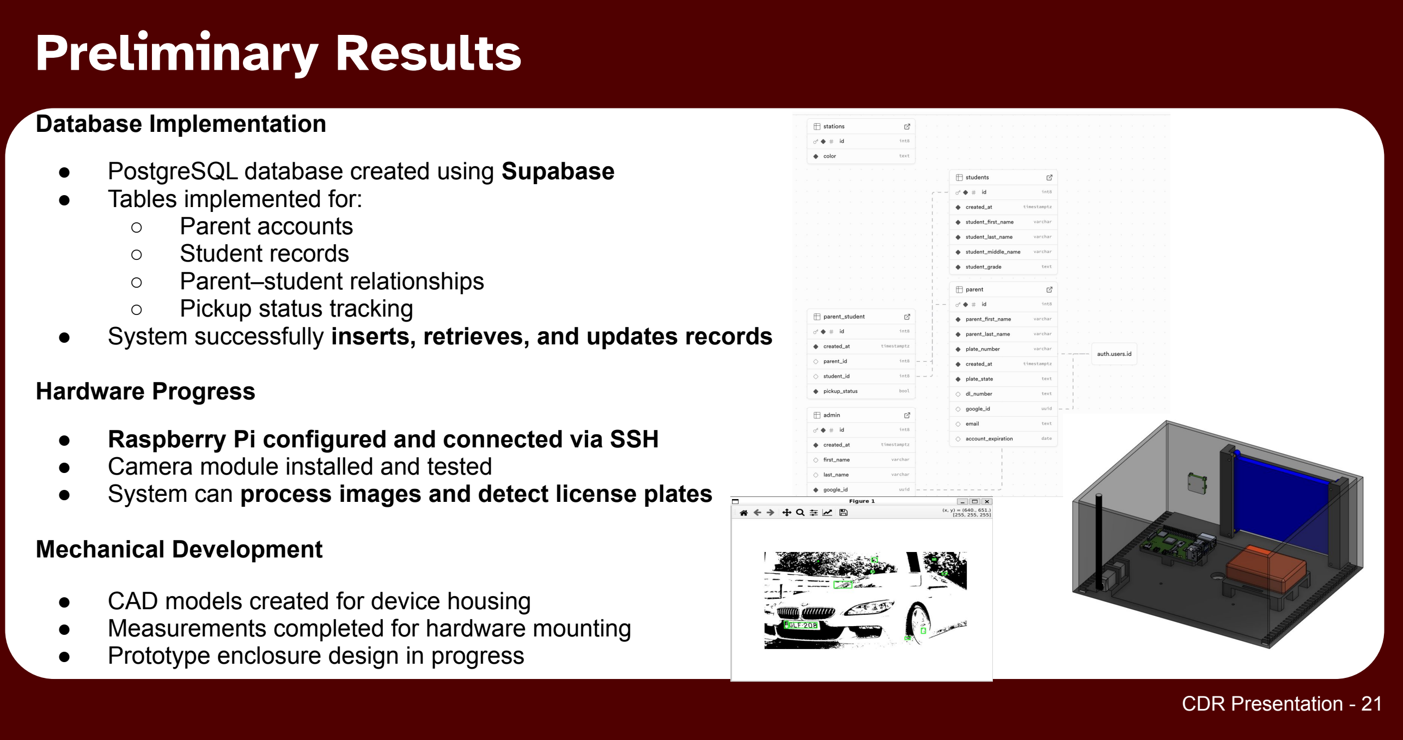
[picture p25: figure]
Preliminary Results; Database Implementation; ● Tables implemented for: ○ Parent accounts ○ Student records ○ Parent–student relationships ○ Pickup status tracking; Hardware Progress; ● Camera module installed and tested; Mechanical Development; ● CAD models created for device housing

- PostgreSQL database created using Supabase
- System successfully inserts, retrieves, and updates records
- Raspberry Pi configured and connected via SSH
- System can process images and detect license plates
- Measurements completed for hardware mounting
- Prototype enclosure design in progress

Questions?; Thanks for listening!

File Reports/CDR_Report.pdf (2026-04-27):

# Car Rider Pickup System

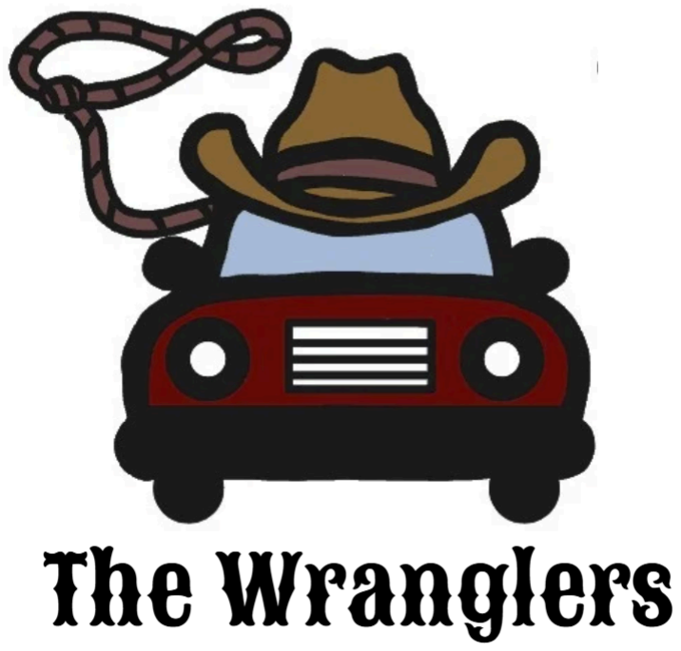
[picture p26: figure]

# Critical Design Review

# The Wranglers

Haya Abusada
Jake Hewett
Jayden Pearson
Jack Uehlinger
Sara Vorhaben

## Department of Computer Science Texas A&M University

## Date: 3/18/2026

TAMU CSCE 483 Critical Design Review | 1/20

## Table of Contents

1 Introduction | 3
2 Proposed design | 4
2.1 Updates to the proposal design (if applicable) | 4
2.2 System description | 4
2.3 Complete module-wise specifications | 6
3 Project management | 10
3.1 Updated implementation schedule | 10
3.2 Updated validation and testing procedures | 12
3.3 Updated division of labor and responsibilities | 14
4 Preliminary results | 16
5 References | 20

### 1 Introduction

School pickup lines in the United States have become crowded and inefficient. The overwhelming majority of students now rely on car rides. This rise results in long wait times, traffic jams on local highways, and serious safety risks for both students and drivers. Current technologies like manual apps and geofencing often depend on unreliable GPS, require active parent involvement, or consume a lot of staff time. To fill this gap, our team created an Automated School Pickup System. This modular, camera-based solution aims to simplify vehicle identification and student pickup without needing manual check-ins or constant staff support.

School pickup via the car rider line has been increasing in the US over the years leading to an increase in line length and pickup time. Now, over 70% of students are picked up from school via the car rider line. Car rider lines have become congested, posing a safety issue for both the students and other drivers. With more students attending school, car rider lines have become too slow and cause parents to wait up to over an hour in line leading to frustration. Some studies show that the car rider pick-up line starts to form 1-2 hours before school actually gets out, which leads to traffic backing up local highways and streets, and even frequent accidents. Inclement weather further slows the line, as students who ride the bus or bike to school will often be picked up by their parents in the car rider line to avoid the weather. Additionally, 5-10 staff members are required to set up and run the pickup process, diverting their time away from the education of students. An automated system is needed to streamline the pick-up process to decrease delays and safety issues.

The project's goal was to create a system that automates the car pickup process to significantly cut down on wait times and improve safety. Our objectives included making weather-resistant hardware modules, integrating License Plate Recognition and QR Code Scanning with low-power microcontrollers, building a reliable hybrid network with Zigbee and Wi-Fi, and making sure the system meets the strict safety standards of the Texas Family Code on student release

The system design has four interconnected modules: a tripod-mounted Car Entrance Module with a camera and Raspberry Pi, a Zone Pickup Module for staff management, a Main Server for database logic, and a Kids Waiting Module with a large indoor display. When a vehicle enters the line, the entrance module captures the license plate or QR code, processes the image on-site, and sends the data through a low-power Zigbee mesh network to the server. The server quickly matches the plate with the student database and updates the displays, directing the driver to a specific zone and alerting the student inside to go to that zone. The design includes 3D-printed housings that can withstand 20 mph winds and uses rechargeable battery banks, making the system portable and independent of the school’s power supply.

The system aims for key performance goals, targeting under 5 seconds of processing time from image capture to display update and a 30% reduction in overall pickup time. To ensure safety, the identification algorithms are designed to achieve 100% accuracy in matching students with authorized guardians. The hardware setup focuses on durability and modularity, allowing component replacement in less than 15 minutes.

### 2 Proposed design 2.1 Updates to the proposal design (if applicable)

The project as a whole remains unchanged from the original design. No new developments have been made in open source, free OCR software or school car rider line pickup systems. The only alternative considered has been using YOLO to detect if a car is in frame to ensure a license plate will be present in the photo, thus saving processing power, time, and energy. However, this has not been implemented since it is unclear if we would need such an optimization in general to achieve the speeds and battery life required. No changes have been made in the budget.

### 2.2 System description

High-Level Block Diagram:


Figure 1: High-level block diagram of the system. The car entrance module will communicate with the zone pickup module through a wireless network called Zigbee. The zone pickup module, main server module, and kids waiting module will all have access to WiFi while the car entrance module will relay information solely through Zigbee.
Car Entrance Module:
Functional Description:
The Car Entrance Module will be placed at the entrance of the pickup line, on the sidewalk next to the road. The side of the module that contains the display and camera as seen in figure 2 will face the road, with a clear view of the approaching cars. The camera will take a picture of the car, and the module will run recognition software to identify the parent/car. The module will send a small packet to the zone pickup module, using zigbee, that contains the identification. The module will wait for a response from the zone pickup module, and then update the display accordingly. The display will show the kid of the parent, and instructions on which zone to proceed to.

Zone Pickup Module:

Functional Description:
The Zone Pickup Module will be placed at the location of the pickup zones, which is also outside. The three main purposes of this module are to display pickup information on a screen for staff and kids to see, to act as a hub for the zigbee wireless communication, and to allow staff to update the system once a kid has been picked up. The laptop will display the website that shows the zone pickup information as seen in figure 3. This information will include each separate zone with a list of kids that are being picked up at each zone. This module will receive packets of information from the Car Entrance Module, and relay that information to our Main Server Module using WiFi. It will then relay any updates from the Main Server Module to the Car Entrance Module using the zigbee connection. The phones will be held by each zone attendant, allowing them to see information regarding their current zone. The zone attendant will press a button on the phone once a kid has been picked up from their zone, allowing the website to be updated automatically.

Main Server Module:
Functional Description:
The Main Server Module will act as the command center for all modules, and it will be hosted on a computer located in the school’s office. The main server has 4 main functions:
1. Host a website that is displayed on the screens in the Zone Pickup Module and the Kids Waiting Module. The website will be updated in real time depending on the information it receives from the Zone Pickup Module. This information will include an identifier (license plate, QR code) and signals when a kid has been picked up at a zone.
2. Connect to a database that contains information about the kids parents, pickup schedule, and identifier (license plate, QR code). The server will query the database when it receives an identifier, and relay the information to the Zone Pickup Module accordingly to send to the Car Entrance Module.
3. Handle information update requests from parents. Parents will have the option to submit a request to update their information using the website. Once approved by an administrator, the server will automatically update the database.
4. Send updates to the display in the Car Entrance Module. Once the server queries the database and finds the parent/kid matching the identifier, it will send that information to the Car Entrance Module to update the display. The way this connection works is:
a. Server ←→ WiFi ←→ Zone Pickup Module ←→ Zigbee ←→ Car Entrance Module

Kids Waiting Module:
Functional Description:
The Kids Waiting Module will consist of a large display, which will show the website. This display will be placed where the kids are waiting to be called. Once an identifier has been read, the server will update the website and a new kids name will appear under a zone. This will inform the staff and the kid which zone to go to.

### 2.3 Complete module-wise specifications

Car Entrance Module:
Diagram:


Figure 2: Blueprint for the car entrance module. The housing will be placed on a tripod, and the display and camera will be placed in view of the car line. The antenna will exit the housing from the side, while the microcontroller and battery will be fully enclosed.

Hardware:
Description: This module will not have access to external power supplies or connections such as WiFi, therefore it needs to be completely self-powered. A sufficient rechargeable battery will be used to power the module, while a microcontroller is used for processing. The microcontroller will have several inputs connected to it, each with its own distinct purpose. A camera will be connected to the microcontroller to take images, a display will be used to display information, and a zigbee antenna will be used to transmit information. All of these hardware components will be enclosed in a 3D printed housing, which will protect the components from overheating in the sun and from light rain. The housing will be mounted on top of a tripod, so the display is readable by someone sitting in a car while the camera can have a proper view of the approaching cars.
Circuit Diagram:


Figure 3: Circuit diagram of the car entrance module.

Software:
Description: The software will be trying to read from pictures that are frequently being taken. In order to help with plate recognition, code has been written to turn each image into an ultra-high contrast one, making darker colors in the image black, and lighter colors white. Once a string of characters recognised as a license plate is found, that plate will be sent to the server using zigbee. Directions for where the parents need to go will be received via the zigbee antenna.
Interfaces: Based on whether or not the plate is recognised, the screen will display instructions for where the parents need to go.

Parts List:

Table 1: A parts list of materials that are needed to build the car entrance module.

Car Entrance Module | Amount Needed | Cost per Unit | Total Amount
Tripod | 1 | $22 | $22
Raspberry Pi | 1 | $75 | $75
Raspberry Pi Camera | 1 | $55 | $55
Zigbee Antenna | 1 | $27 | $27
Rechargeable Battery | 1 | $40 | $40
7-inch display | 1 | $38 | $38
Mounting Screws | ~20 | $8 (600 pcs) | $8

Wires | ~5 | $10 (240 pcs) | $10
Total Cost | $275

Zone Pickup Module:
Diagram:


Figure 4: Blueprint for the zone pickup module. The antenna will be connected to the laptop, while the laptop displays the kids module pickup screen. The phones will be held by each zone attendant, and will display information about each specific zone.

Hardware:
Description: The hardware in this module will consist of a laptop, a zigbee antenna, and a cell phone for each zone. Because this module is also outside, it will need to be self-powered like the Car Entrance Module. The zigbee antenna will rely on power from the laptop battery, and we will assume that the laptop and phones used are fully charged when starting.

Software:
Description: Using zigbee, the license plate information will be received for the Car Entrance module, then compared to all the plates in the database. If a matching plate is found, then an algorithm will be run to determine where to send the parent to minimize wait times. The station decided by the algorithm will be sent back to the Car Entrance module. The student name associated to that plate will then be assigned to the same station. When a child is picked up, the teacher/volunteer will check off that the child will be picked up.
Interfaces: The laptop will display all of the stations along with the kids headed to each station. Each of the teachers or volunteers at the stations will have phones displaying the children that are next to be picked up at the station.

Parts List:

Table 2: A parts list of materials that are needed to build the zone pickup module.

Zone Pickup Module | Amount Needed | Cost per Unit | Total Amount
Zigbee Antenna | 1 | $27 | $27
Total Cost | $27

Main Server Module:
Diagram:


Figure 5: Rough blueprint for the main server module. The module will contain a separate computer that hosts a server and controls the different modules, for example the website displayed in the zone pickup and kids waiting module, and the display on the car entrance module.

Hardware:
Description: The hardware required for this module will consist of a single computer.

Software:
Description: This module needs to be connected to the database, as this module will be where the database will be queried, and results sent back to each of the modules.
Interfaces: This module will take in identifiers, that will assign adults to children, and information update requests from parents if the info in the database/website needs to be updated and approved.

Parts List:
The main server module will be hosted from a computer in the schools administration office, meaning that a pre-existing computer will be sufficient for this module. This results in this module's total cost being $0 as seen in Table 3.

Table 3: A parts list of materials that are needed to build the main server module.

Main Server Module | Amount Needed | Cost per Unit | Total Amount
Total Cost | $0

Kids Waiting Module:
Diagram:


Figure 6: Rough blueprint for the kids waiting module. The module will contain a large display that displays the pick up line instructions website.

Hardware:
Description: The hardware for this module will consist of a large display such as a projector or a TV.

Software:
Description: This module will simply be displaying a page on our website that displays the queued children at each of the zones. This module will not be running any software itself.
Interfaces: This module has no inputs nor outputs, simply a display showing the website page made for it.

Parts List:
The kids waiting module will access the website and show the pick up line instructions. Assuming the kids are waiting in a gym or cafeteria, we will assume the school has access to a large display already (large projector, TV). This results in this module’s total cost being $0 as seen in Table 4.

Table 4: A parts list of materials that are needed to build the kids waiting module.

Kids Waiting Module | Amount Needed | Cost per Unit | Total Amount
Total Cost | $0

### 3 Project management 3.1 Updated implementation schedule

Since our design was updated to allow cars to scan QR codes, our schedule was updated to match these changes. In order to make this change to a QR Scanner an additional task of designing and integrating the QR scanner was added to our taskboard. The Gantt Chart that reflects these changes can be seen below.


Figure 7: Gantt Chart
However, even with this adjustment, our critical path remains the same at 45 days. Additionally, the chart shows the progress that we have made to date. Tasks highlighted in green have been completed with the red line indicating today’s date The updated schedule can be found in the table below.

Table 5: Schedule of Tasks
Name | Start Date | End date | Status
Build Database | 2/16/2026 | 2/21/2026 | Done
Website: Designs | 2/16/2026 | 2/18/2026 | Done
Website: Frontend | 2/18/2026 | 2/25/2026 | Done
Website: Backend Development | 2/21/2026 | 3/3/2026 | Done
Website: Backend Connection to Server | 3/23/2026 | 3/26/2026 | Not Started
Website: Receive Server responses and update site | 3/26/2026 | 3/30/2026 | Not Started
Camera: QR Code Integration | 2/28/2026 | 3/21/2026 | In progress
3D casing | 2/28/2026 | 3/6/2026 | In Progress
Write SQL Database Querying For Results | 3/3/2026 | 3/7/2026 | In Progress
Server: setup and connection | 3/3/2026 | 3/7/2026 | Not started
Camera: Raspberry PI camera setup and operation | 2/18/2026 | 2/28/2026 | Done
Camera: Raspberry PI Screen Response Output | 3/21/2026 | 3/26/2026 | Not started
Zigbee: setup | 3/6/2026 | 3/18/2026 | Done
Order parts | 2/16/2026 | 2/18/2026 | Done
Zigbee: Connection from website the server | 3/18/2026 | 3/20/2026 | Not started
Zigbee: Connection from hardware to the Website | 3/18/2026 | 3/20/2026 | Not started
Server: Receive camera info and query the database | 3/26/2026 | 3/30/2026 | Not stared
Server: Format Server Responses to Website and | 3/30/2026 | 4/2/2026 | Not Started

Display
System testing | 4/2/2026 | 4/24/2026 | Not Started

### 3.2 Updated validation and testing procedures

To be considered successful, the school pick up system must have a 100% accuracy rate at determining and delivering a child to their parent quickly. The system should be intuitive, easy to use, and require minimal effort for staff to set up. The system requirements are listed below.
Marketing Requirements
1. Make the pickup process faster for parents
2. The system should be easily updated
3. The system should be low cost
4. The system should be easy to use/install
5. Information must be validated if updated or inserted
6. Student safety should be ensured (information, physical, etc.)
7. The system should be reliable

Engineering Requirements
Marketing Requirements | Engineering Requirements | Justification
1 | Pickup time should be reduced by 30% per 100 kids. The time from the car entering the view of the camera to information being displayed should be no more than 5 seconds. | Based upon an average pickup time of 45 minutes, an automated system can obtain a significant improvement. Image processing, information relay, and database queries should have little delay.
4 | 7 inch (diagonal) display screen to give station and process instructions clearly. | 7 inches is considered the perfect size for basic instructions. Most car screens range between 7-9 inches.
1, 6 | Per Texas Family Code, ensure that students are referred to authorized parents 100% of the time. | By following the code, the system will only send students to the correct cars, which guarantees the student’s safety and prevents confusion and delay.
6 | Private Information stored in the database should be encrypted using 128 bit encryption. | Encrypted communications about student data prevents possible eavesdropping of sensitive student data, contributing to the overall safety

| | of the student.
7 | Should have a stable connection from within 1 kilometer, stable power to all components. | Connection methods (WiFi, Ethernet Bridge, IoT Data Sim) are all reliable well over 1 kilometer. A power bank will be able to provide substantial power to the hardware system.
1,6,7 | Should correctly identify/assign parents to kids 100% of the time. | Based on current AI image recognition capabilities, an accuracy of 100% is achievable.
3 | The costs for developing the system should not exceed $300. | This is based upon hardware cost analysis.
2,4,5 | The system should allow parents to submit a request to the school to update information and the school should receive the request all within 1 minute. | The modification is easy to make, as evidenced by the speed of the interaction. Since this process ends in a request, the school therefore validates the request, satisfying 5.
4 | The system should have a modular design such that failed components can be replaced by a technician in under 15 minutes. | Minimal downtime to prevent the loss of efficiency (30% quicker pickup time).
4,7 | The system should be mounted correctly on a tripod to ensure stability and prevent hazards. Sandbag/Weights of at least 1 pound to keep it grounded. | For 20mph wind 5-15 pounds of ballast is generally needed to prevent movement.
7 | The software will comply with the Digital Millennium Copyright Act. | Compliance is required by law.
2,4,5,6 | Staff should be able to access databases with provided credentials and view all parent to children links. | Student information should be easily alterable in case of changes in student transportation methods as well as verification of student/parent information.
4,7 | The system should be able to withstand 20mph wind. | Average wind speeds in College Station are 7-10 mph.
1 | Minimum 40inch (diagonal) display screen to give station and process instructions clearly inside in the pickup . | Students should be able to see the screen to know it is their turn to leave when their parents arrive.
6 | The website must prevent unauthorized | Student information should be

views and edits and require school approval for changes.

protected and secure against unauthorized modification.

Safety Requirements
- The system should ensure students are referred to authorized parents 100% of the time.
- The system should require information to be updated every year

Maintainability Requirements
- The system should have a modular design such that failed components can be replaced by a technician in under 15 minutes.
- The system should be able to modify the number of stations available for pickup

In order to demonstrate proof of a working system, a video will be taken of the system in action. The video will show the full process from the car entering the pick up line to when the kid would enter the car and exit the line. Additionally, a live demonstration of a QR code scanning can be done to demonstrate the ease of use for parents and proof of a working system.

### 3.3 Updated division of labor and responsibilities

The Car Rider Pickup System project is being developed by a team of five members. Each member is responsible for a specific subsystem of the project to ensure efficient development and integration of hardware, software, and user interfaces. The responsibilities are divided across website development, hardware integration, database management, and mechanical design. Regular weekly meetings are used to coordinate progress and ensure that all subsystems remain compatible with one another.

Haya Abusada – Frontend Development and System Integration

Haya is responsible for the development of the user-facing components of the web system, particularly the landing page and kids pickup module interface. Her work focuses on implementing the visual layout and interactive features using React while ensuring the interface connects correctly to the backend database. She is also responsible for deploying the website and ensuring the frontend communicates correctly with the Supabase PostgreSQL database. Additionally, Haya assists with integrating the pickup station module interface used by staff to confirm student pickups.

Deliverables

- Landing page UI design and implementation – Feb 20
- Kids pickup module interface – Feb 27
- Integration of frontend with database – Mar 6
- Deployment of the web application – Mar 27
- Final UI adjustments and testing – Apr 3rd
- Implement software logic with hardware + testing - Apr 10th
- Full System testing - Apr 24th

Sara Vorhaben – Backend Development and Parent Portal

Sara is responsible for developing the backend infrastructure that supports the website and database interaction. Her work includes implementing the parent portal functionality, handling authentication, and ensuring data from the database is correctly retrieved and displayed. She is also responsible for connecting the backend services to the React frontend and managing the logic that handles student pickup requests and account management.

Deliverables

- Parent portal interface design – Feb 20
- Backend API integration with database – Feb 27
- Google authentication implementation – Mar 6
- Student pickup request logic – Mar 27
- Backend validation and testing – Apr 3rd
- Implement software logic with hardware + testing - Apr 10th
- Full System testing - Apr 24th

Jake Hewett – Database Architecture and Administrative Interface

Jake is responsible for designing and managing the database structure that stores all system data. This includes creating and maintaining the PostgreSQL tables used to track parent accounts, students, pickup status, and station assignments. He also develops the administrative interface used by school staff to manage system data. His responsibilities include maintaining database performance and ensuring secure data handling.

Deliverables

- Initial database schema design + tables – Feb 20
- Administrative website interface – Feb 27
- Administration search and edit functionalities - Mar 6th
- All software page connections/buttons complete - Mar 27th
- Database performance optimization and testing – Apr 3rd
- Implement software logic with hardware + testing - Apr 10th
- Full System testing - Apr 24th

Jack Uehlinger – Hardware and Camera Integration

Jack is responsible for the hardware subsystem of the project, particularly the integration of the Raspberry Pi and camera system. His work focuses on capturing vehicle images and preparing them for license plate recognition or QR code processing. He also manages hardware communication and ensures the system can reliably collect data for the pickup process.

Deliverables

- Raspberry Pi configuration and SSH setup – Feb 20th
- Camera hardware setup and testing – Feb 27th
- Image capture testing and automation – Mar 6th
- Integration with recognition system – Mar 27th
- Final hardware validation – Apr 3rd
- Zigbee and communication implementation + testing - Apr 10th
- Full System testing - Apr 24th

Jayden Pearson – Mechanical Design and Enclosure Development

Jayden is responsible for the physical housing and mechanical design of the system components. His work includes creating CAD models for the device housing and ensuring that the system components can be securely mounted and protected from environmental conditions. He also manages the fabrication and assembly of the physical system modules.

Deliverables

- CAD design of system housing + Measurements – Feb 20
- Set up Zigbee connections – Feb 27th
- 3D modeling and prototype enclosure – Mar 6th
- Fabrication and assembly of physical components – Mar 27th
- Final enclosure testing – Apr 3rd
- Zigbee and communication implementation + testing - Apr 10th
- Full System testing - Apr 24th

Team Coordination

The team meets weekly to review progress, address technical challenges, and plan future work. Communication is maintained through shared tools such as Discord, GitHub, and Google Drive. Each member provides weekly progress updates and documents accomplishments in weekly reports. These meetings ensure that software, hardware, and mechanical components remain compatible as the system progresses toward final implementation.

### 4 Preliminary results

Several components of the Car Rider Pickup System have already been successfully implemented and tested during the early development stages. These preliminary results demonstrate that the core architecture of the system is functional and that the individual subsystems are progressing according to schedule.

Website Development

The primary user interface for the system is a web-based application that allows parents and school staff to interact with the pickup system. The frontend for all major pages has been developed using React, including the landing page, parent portal, administrative pages, and the kids pickup module interface.

The parent portal allows authenticated users to log in using Google authentication and access their account information. Parents can register their students and update license plate information. The system connects to a PostgreSQL database hosted on Supabase, enabling real-time retrieval and storage of user data.

At the time of the Critical Design Review, the website is nearly complete and functional. The interface successfully communicates with the backend database, allowing parent and student records to be stored and retrieved correctly. Additional testing is ongoing to ensure the system performs reliably under multiple user interactions.

Link to Website (https://thewranglers.onrender.com/)

Database Implementation

A PostgreSQL database has been created and deployed using Supabase to store all system data. The database includes tables for parent accounts, student records, and relationships between parents and students. These tables allow the system to track which parents are authorized to pick up which students and to store relevant account information.

Initial database testing has confirmed that records can be successfully inserted, retrieved, and updated through the website interface. The database has also been modified to include additional fields such as student grade information and login-related attributes based on design discussions during team meetings.


Figure 8: Database Tables and Relationships


Figure 9: Database inserts connected to software

Hardware Setup

The hardware platform for the project has also progressed significantly. A Raspberry Pi system has been configured and connected to the network using SSH. The camera module has been tested successfully and can capture images that will later be used for vehicle identification and recognition algorithms.

Testing confirmed that the Raspberry Pi camera can reliably capture images and store them for processing. This capability will later be used for license plate recognition or QR code verification, depending on the final system configuration.

Below is a captured image using the raspberry pi camera.


Figure 10: Image captured from camera connected to raspberry pi

And here is how license plates are picked up.


Figure 11: License plate picked up via camera on a car

Mechanical Design

The mechanical design of the system housing has begun, and CAD models for the device enclosure have been created. These models ensure that all hardware components can be securely mounted and protected. Measurements of hardware components have been completed to support the design of the enclosure.


Figure 12: 3D Enclosure design

System Communication and Development Environment

The development environment for the project has been successfully established. The team has configured communication and collaboration tools including GitHub for version control, Discord for communication, and Google Drive for document sharing.

Github (https://github.com/JackUehlingerTAMU/TheWranglers) and Google Drive (https://drive.google.com/drive/u/0/folders/0ALKTHytaWO2gUk9PVA)

These tools allow team members to collaborate effectively and maintain synchronized development across hardware, software, and mechanical components.

Current System Status

Overall, the project is currently progressing according to schedule. Major foundational components, including the database infrastructure, website interface have already been implemented and tested. The next phase of development will focus on integrating these components into a fully functional system capable of automating the school pickup process.

### 5 References

[1] College Towns, “The School Car Pickup Line Is a National Embarrassment”, College Towns, 2025. [Online}. Available: https://www.collegetowns.org/p/the-school-car-pickup-line-is-a-national

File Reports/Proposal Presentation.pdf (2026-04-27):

Car Rider Pickup System for Schools

# Haya Abusada, Jake Hewett, Jayden Pearson, Jack Uehlinger, Sara Vorhaben

# Problem Background

- Over 70% of students are now picked up via car, creating massive congestion.
- Parents wait up to 1 hour, with lines often forming 1-2 hours before dismissal.
- Queues spill onto local highways, causing traffic backups and increasing accident risks.
- Inclement weather increases delays as bus and bike riders often switch to the car line.

## - The manual process requires 5-10 staff members daily, diverting them from educational

duties.

Proposal Presentation - 2

# Needs Statement

## School pickup via the car rider line has been increasing in the US over the years leading to an increase in line length and pickup time. Now, over 70% of students are

picked up from school via the car rider line. Car rider lines have become congested,

posing a safety issue for both the students and other drivers. With more students attending school, car rider lines have become too slow and cause parents to wait up to over an hour in line leading to frustration. Some studies show that the car rider pick-up line starts to form 1-2 hours before school actually gets out, which leads to traffic backing up local highways and streets, and even frequent accidents. Inclement weather further slows the line, as students who ride the bus or bike to school will often

be picked up by their parents in the car rider line to avoid the weather. Additionally, 5-10

## staff members are required to set up and run the pickup process, diverting their time away from the education of students. An automated system is needed to streamline the

pick-up process to decrease delays and safety issues.

# Goal and Objectives

## Goal

The goal of this project is to design and prototype a system that will help automate the car rider pick up process at schools. The system is built to reduce the amount of time necessary to pick up students from school.

## Objectives

- The system will allow parents to update their information (license plate numbers, approved adults for pickup, car rider schedules) via a website with approval from a staff member of the school.
- The system will read the marker on the car (license plate, QR code, nametag) as it enters the pickup line and send the information to a server.
- The server will identify the parent and child associated with the car marker, and update a display at the entrance of the pickup line to direct the car to the proper station.
- The laptop at the front of the school is updated to inform the students and staff which child is being picked up, and which zone to go to.

# Goal and Objectives - Requirements

# Marketing Requirements

1. Make the pickup process faster for parents 2. The system should be easily updated 3. The system should be low cost 4. The system should be easy to use/install 5. Information must be validated if updated or inserted 6. Student safety should be ensured (information, physical, etc.) 7. The system should be reliable

# Goal and Objectives - Requirements

Marketing Requirements | Engineering Requirements
1 | Pickup time should be reduced by 30% per 100 kids. The time from the car entering the view of the camera to information being displayed should be no more than 5 seconds.
4 | 7 inch (diagonal) display screen to give station and process instructions clearly.
1, 6 | Per Texas Family Code, ensure that students are referred to authorized parents 100% of the time.
6 | Private Information stored in the database should be encrypted using 128 bit encryption.
7 | Should have a stable connection from within 1 kilometer, stable power to all components.
1,6,7 | Should correctly identify/assign parents to kids 100% of the time.
3 | The costs for developing the system should not exceed $300.
2,4,5 | The system should allow parents to submit a request to the school to update information and the school should receive the request all within 1 minute.

# Goal and Objectives - Requirements

Marketing Requirements | Engineering Requirements
4 | The system should have a modular design such that failed components can be replaced by a technician in under 15 minutes.
4,7 | The system should be mounted correctly on a tripod to ensure stability and prevent hazards. Sandbag/Weights of at least 1 pound to keep it grounded.
7 | The software will comply with the Digital Millennium Copyright Act.
2,4,5,6 | Staff should be able to access databases with provided credentials and view all parent to children links.
4,7 | The system should be able to withstand 20mph wind.
1 | Minimum 40inch (diagonal) display screen to give station and process instructions clearly inside in the pickup .
4 | The system should have a modular design such that failed components can be replaced by a technician in under 15 minutes.
4,7 | The system should be mounted correctly on a tripod to ensure stability and prevent hazards.
Sandbag/Weights of at least 1 pound to keep it grounded.

# Literature Review -

## Overview

- Schools use technology to reduce pickup congestion, improve safety, and streamline communication

### - These systems inform our design, though none use our proposed method

## Existing Systems

- PikMyKid – App-based digital car line; parents announce arrival, staff release students via dashboard

### - Beeline – Uses geofencing to detect vehicles and alert staff automatically - Car-Pool App – Geofencing and ETA alerts to stage students before arrival - iSchoolRide – GPS-based parent check-in for just-in-time student release - Kids Pick Up App – QR code scanning to verify authorized pickups

## Key Takeaway

### - Current solutions reduce manual effort and congestion - Most still rely on parent apps, GPS, or staff scanning and verification

# Design Constraints and Feasibility

Technical and Temporal Constraints

- Maximum of 5 seconds from image capture to display update
- Identification accuracy must be 100% to ensure safety and efficiency
- Connection between the system parts must be reliable

Physical and Environmental

- Needs to withstand outdoor elements (wind and rain)
- Needs to be portable and stable with modular parts, mounting, and power supply to reduce system downtime and speed up repair and maintenance

Economic

- Must cost $250 or less, necessitating cost-effective components

Feasibility

- Core technology, such as Python image processing and Wi-Fi, is well documented and achievable
- Main challenge will be creating a fast and efficient system within our budget

# Evaluation of alternative solutions

Proposal Presentation - | 10
Solution | Pros | Cons
Manual Pickup App (PikMyKid) | Easy to implement; low cost; reduces paperwork | Requires staff queue management; no automated vehicle identification
Integrated Dismissal System (Beeline) | Improves communication; integrates with school systems | Requires training and infrastructure; still staff-monitored
Geofencing (Car-Pool App) | Real-time arrival alerts; reduced manual check-ins | Dependent on GPS accuracy, mobile devices, and connectivity
GPS Check-In (IschoolRide) | Keeps students inside until arrival; reduces idle staging | Relies on parent app usage and accurate GPS; staff verification will still be needed
QR Codes (Kids Pick Up App) | Simple, affordable; no cellular service required | Requires staff scanning; affected by glare, weather, and visibility

All alternatives improve organization but still rely on staff actions or parent interaction, limiting full automation.

# Proposed design - High-Level Block Diagram

● Need 4 main modules; ○ Car Entrance Module; Located at entrance of line; ○ Zone Pickup Module; Located at pickup zones; ○ Main Server Module; Located inside school’s office; ○ Kids Waiting Module; Located at area where kids wait; to be called (gym, cafeteria, outside) ● Zigbee - low power wireless mesh network standard 0-100m (similar to Bluetooth); packets of data; ○ No stable WiFi at entrance; Proposal Presentation - 11

- More reliable than Bluetooth for small
- Avoid Bluetooth interference from passing cars

# Proposed design - High-Level Block Diagram

Proposal Presentation - 12; Car line entrance; Car Stations; Car Entrance Module; Main Server Module; Kids Waiting Module; Zone Pickup Module

# Proposed design - Car Entrance Module

● Primary function is to complete license plate recognition; ○ Camera takes frequent pictures ○ Processes image for license plate; Zigbee ● Display for parents; parent to specific zone ● 3D printed housing; light rain; Proposal Presentation - 13; Example packet of info sent:; { “event”: “license_plate_detected”, “plate”: { “number”: “ABC1234”, “state”: “TX”; Example packet of info received:; { “event”: “update_display”, “info”: { “name”: “John Doe”, “zone”: “1, red”

- Once found, send license plate number using
- Wait for results from server, then update display to confirm correct kid and direct
- Protect components from direct sunlight and

# Proposed design - Zone Pickup Module

for each zone ○ Removes kids name from list; Proposal Presentation - 14; ● 3D printed housing ○ Block direct sunlight and light rain

### - Act as a receiver for Zigbee communication - forward info to server (WiFi) - Also forward info from server to car entrance module (Zigbee)

- Large screen to display website at the zones - lists of kids being picked up at each zone
- Button submodule - allows staff member to press a button when a kid is picked up at a zone, one button

# Proposed design - Main Server Module

● Located in school’s office ● Host a website - updated in real time; waiting modules; numbers.; number; parents (once approved by admin); ○ After querying database; Proposal Presentation - 15

- Displayed on screens in zone pickup and kids

### - Connect to database that contains info about all kids parents, pickup schedule, and license plate

- Query the database to find info given license plate
- Update database based on requests made by

### - Send updates to display in car entrance module

Server ←→ WiFi ←→ Zone Pickup Module ←→ Zigbee ←→ Car Entrance Module

# Proposed design - Kids Waiting Module

Proposal Presentation - 16

## - Large TV screen where kids are gathered to wait (gym, cafeteria, outside)

## - Display website to inform staff and kids who is being picked up, and what zone to

# Approach for design validation

## Small, foundational testing first

## - Verify connectivity to web server and database - Display text found by the camera directly to the screen it is connected to - Ping router from the car entrance module to verify connectivity - QUERY database to ensure proper initialization

## System testing comes next

## - Packets should be sent to the database, should return student names - Screens directing drivers and students should update in no more than 5 seconds - Web server flags incoming requests to alter database to admin page

# Economic analysis and budget

Economic Viability:; Elementary and Middle Schools; ● Save Parents & Teachers Time; produced in bulk

- National Center for Education: There are 70,055 Public Pre-Kindergarten,

### - Each school has to have a pickup system - Could also be used in Daycares and Private Schools

### - Allow them to spend time in more productive ways

## - Production costs for items and the 3D casing would decrease if ordered and

# Economic analysis and budget

Sustainability:; ● Limited Customer maintenance:; ○ Charging of rechargeable batteries ○ Yearly website database setup ○ Software updates

## - Raspberry Pi, Camera and Zigbee are all available from multiple vendors - Standard software frameworks are used to ensure long-term support

# Economic analysis and budget

Manufacturability:; read; pickup

## - Camera alignment/height needs to be correct to ensure licence plate can be

## - Casing of Camera designed to withstand wind and rain - Modular Design allows for easy replacement of broken components - In the event that the license plate doesn’t match, we have a separate spot for

## - End-to-End is testable as well as component based testing - Compliant with student privacy regulations

# Economic analysis and budget

## - Car Entrance Module

Car Entrance Module | Amount Needed | Cost per Unit | Total Amount
Tripod | 1 | $22 | $22
Raspberry Pi | 1 | $75 | $75*
Raspberry Pi Camera | 1 | $55 | $55*
Camera Lens | 1 | $50 | $50*
Zigbee Antenna | 1 | $27 | $27
Rechargeable Battery | 1 | $40 | $40
7-inch display | 1 | $38 | $38*
Mounting Screws | ~20 | $8 (600 pcs) | $8
Wires | ~5 | $10 (240 pcs) | $10
Total* (without including components provided) | $107
Total Cost | $325
- Total* (without including components provided): $107

## - Total: $325

# Economic analysis and budget

## - Zone Pickup Module

Zone Pickup Module | Amount Needed | Cost per Unit | Total Amount
Raspberry Pi | 1 | $75 | $75*
Zigbee Antenna | 1 | $27 | $27
Rechargeable Battery | 1 | $40 | $40
27-inch monitor | 1 | $97 | $97*
Push Buttons | 6 (depending on # of zones) | $11.50 (24 pcs) | $11.50
Mounting Screws | ~20 | $8 (600 pcs) | $8*
Wires | ~15 | $10 (240 pcs) | $10*
HDMI Cord | 1 | $4 | $4
Total* (without including components provided) | $82.50
Total Cost | $272.50
- Total* (without including components provided): $82.50

## - Total: $272.50

# Economic analysis and budget

● Main Server Module; by the school; Main Server Module; Amount Needed; Cost per Unit; Total Amount; Total Cost; ● Total: $0; ● Kids Waiting Module; 55-inch TV; Total* (without including components provided); ● Total* (without including; components provided): $0 ● Total: $180

## - Assuming server is hosted on a computer used

# Economic analysis and budget

## - Total budget without any components provided:

## - Total budget with provided components:

Car Entrance Module | $325
Zone Pickup Module | $272.50
Main Server Module | $0
Kids Waiting Module | $180
Total | $777.50
Car Entrance Module | $107*
Zone Pickup Module | $82.50*
Main Server Module | $0
Kids Waiting Module | $0*
Total* | $189.50

### - Note*: 3D printed prototypes not included, FEDC grants $75 allotment for fabrication

# Schedule of tasks - Pert Chart


## - Sara

Proposal Presentation - 25 Critical Path: 45 days

# Schedule of tasks - Gantt Chart


# Schedule of tasks

Name | Start Date | End date | Time | Task description:
Order parts | 2/16/2026 | 2/18/2026 | 2 | Order all remaining parts
Website: Designs | 2/16/2026 | 2/18/2026 | 2 | Create wireframes for Parent Portal Page, Login Screen, Admin Dashboard, and Kids Pickup Status Screen, and get group approval of designs
Build Database | 2/16/2026 | 2/21/2026 | 5 | Create database schema, basic CRUD queries and set up authentication-related database endpoints
Website: Frontend | 2/18/2026 | 2/25/2026 | 7 | Implement approved designs with responsive layouts
Camera: Raspberry PI camera setup and operation | 2/18/2026 | 2/28/2026 | 10 | Install Raspberry Pi OS, enable camera interface, install required libraries and test image capture functionality
Website: Backend Development | 2/21/2026 | 3/3/2026 | 10 | Set up backend framework, connect it to the database, implement authentication and authorization logic, validate user input, and implement basic logging

# Schedule of tasks

Name | Start Date | End date | Time | Task description:
Camera: Raspberry Pi Licence Recognition | 2/28/2026 | 3/21/2026 | 14 | Develop license plate recognition system using Raspberry Pi camera
3D casing | 2/28/2026 | 3/7/2026 | 7 | Design casing for Raspberry Pi camera system
Server: setup and connection | 3/3/2026 | 3/7/2026 | 4 | Configure server environment and set environment variables, and ensure secure database connectivity
Write SQL Database Querying For Results | 3/3/2026 | 3/7/2026 | 4 | Write SQL Queries for pickup to match license plate numbers to authorized parents
Website: Backend Connection to Server | 3/3/2026 | 3/6/2026 | 3 | Deploy backend application to server environment
Zigbee: setup | 3/6/2026 | 3/18/2026 | 5 | Install Zigbee coordinator and modules

# Schedule of tasks

Name | Start Date | End date | Time | Task description:
Zigbee: Connection from hardware to the Website | 3/18/2026 | 3/20/2026 | 2 | Configure server to update Website when hardware sends plate
Camera: Raspberry PI Screen Response Output | 3/21/2026 | 3/26/2026 | 5 | Make the screen show green when recognized license plate number is verified & handle error or unrecognized plate cases
Server: Receive camera info and query the database | 3/26/2026 | 3/30/2026 | 4 | Implement server-side endpoint to receive license plate data from Raspberry Pi, validate input, and query database for matching parent/student
Server: Format Server Responses to Website and Display | 3/30/2026 | 4/2/2026 | 3 | Send verification results to both classroom display system and website frontend
System testing | 4/2/2026 | 4/9/2026 | 7 | Test end-to-end functionality of entire system

# Project management and teamwork

Haya; ● Hardware Design ● OCR Design; Jake; ● Web Applications ● OCR Design; Jayden; ● Hardware Design ● Systems Design; Jack; ● Team Leader ● Systems Design; Sara; ● Database Design ● Web applications; monday.com will be used for project management. It will track dependencies; a timeline for the project; Everyone; ● Software Engineering ● Documentation/ Reports ● Testing

## and division of labor, as well as provide

# Societal, safety and environmental analysis

## Societal:

## - Parents spend less time waiting in line - Teachers spend less time managing pickup and more in classroom

- Kids are less likely to get agitated/distracted leading to less problems for staff/parents

## - The secure system ensures that students are released to the correct parents

## Safety:

## - Ensure that kids end up with the correct parent - No kid is lost in the system or placed incorrectly - Ensure that kids aren’t put in dangerous situations (ex running in the road)

## Environmental:

## - Reduction in vehicle idling

Questions?; Thanks for listening!

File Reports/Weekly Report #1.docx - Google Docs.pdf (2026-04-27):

WEEKLY REPORT and MEETING AGENDA

Report #: | 1 | Project Name: Car Rider Pickup System for Schools
Date: | 2/16/2026 | Prepared by: All Team Members

Agenda for the meeting

### 1. Discuss license plate vs qr code recognition 2. Look at wireframes for the website

3.
4.
5.

Overall accomplishments since last meeting

### 1. Set up all communication methods - Discord, github, drive 2. Hiya ordered parts:

3. Wireframe (https://docs.google.com/presentation/u/0/d/1N-_XUV2rMSEdKnJUqgwT66DcYqOZtxBdcBhvxXKX5aE/edit) designs were completed for website

### 4. Tables were created in our postgreSQL database (supabase)

5.

Tasks completed by each team member since last meeting

Task description | Assigned to | Completed?
| | yes/no
Ordering Parts - Create Part List | Haya | Yes
PI Setup - check connections | Jack | Yes
Website Wireframes | Sara | Yes
Database Setup - Create Tables | Jake | Yes
Create CAD files and environment | Jayden | Yes

Plans for next period

### 1. Camera has the ability to take photos 2. Frontend development of Website 3. Backend development of website

Task assignment per team member (to be completed before the next meeting)

Task description | Assigned to
Website Pages - Front end design (parent) + connect backend to react project | Sara
Website Pages - Front end design (kids module + Landing Page) | Haya
Website Pages - Front end design (admin) | Jake
Consistently Take pictures with the Raspberry PI camera | Jack
Measure dimensions of all parts | Jayden

Project management status

Weekly Report Form. CSCE 483 Computer System Design

### 1. Purchased parts : should come in 2/19 2. Completed wireframes for website 3. Configured PI and set up SSH 4. Set up group communication

Minutes from previous meeting
Please be thorough, a bullet list of 2-3 single-liners is not sufficient
- Removing the screen at the zone pickup module
- Reducing redundant hardware
- License plate alternatives may be better because license plate reader is difficult to implement
- At zone stations, use phone screens to confirm pickup of correct child

Weekly Report Form. CSCE 483 Computer System Design

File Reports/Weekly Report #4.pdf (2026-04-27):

WEEKLY REPORT and MEETING AGENDA

Report #: | 4 | Project Name: Car Rider Pickup System for Schools
Date: | 3/30/2026 | Prepared by: All Team Members

Agenda for the meeting

### 1. Updated Site 2. QR code demo

3.
4.
5.

Overall accomplishments since last meeting

### 1. Made website dynamic to work on phones 2. Physical housing model re-sized to fit required dimensions 3. Set up a time to meet with School (Wednesday at 11:30) 4. Installed and configured windows server and virtual machine (still need to connect to

pi)

### 5. Pi can determine to read either QR code or license plate

Tasks completed by each team member since last meeting

Task description | Assigned to | Completed?
Implement QR code recognition | Jack | Yes
Begin looking into connecting camera software with website | Haya, Jake | Yes
Research QR code (2nd option) methods, Responsive Design | Sara | Yes
Begin 3D Housing physical production | Jayden | Yes

Plans for next period

### 1. Put together system prototype (all parts + 3d print print) 2. Start implementing server/Wifi connection between all different modules 3. Backend coding for camera and database searches 4. Meet with the school 5. Complete Pi software, begin networking

Task assignment per team member (to be completed before the next meeting)

Task description | Assigned to
Setup server | Sara
Begin coding server to camera connection | Haya
Begin coding server to database connections | Jake
Finish license plate recognition and integrate continuous picture taking | Jack
Put together complete system with 3d print and all equipment. | Jayden

Weekly Report Form. CSCE 483 Computer System Design

Project management status

### 1. Our project is running on time according to our Monday board

2.
3.

Minutes from previous meeting
-Contact school coach
-test license plate system in a lot of depth - angles, lighting etc. -

Weekly Report Form. CSCE 483 Computer System Design

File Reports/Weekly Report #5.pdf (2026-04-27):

WEEKLY REPORT and MEETING AGENDA

Report #: | 5 | Project Name: Car Rider Pickup System for Schools
Date: | 4/6/2026 | Prepared by: All Team Members

Agenda for the meeting

### 1. Meeting with coach 2. New housing model design

3.
4.
5.

Overall accomplishments since last meeting

### 1. Met with coach 2. Redesigned housing model to be as small as possible 3. Server has been setup, still working on connectivity

4.
5.

Tasks completed by each team member since last meeting

Task description | Assigned to | Completed?
Setup server | Sara | Yes
Begin coding server to camera connection | Haya | Yes
Begin coding server to database connections | Jake | Yes
Finish license plate recognition and integrate continuous picture taking | Jack | No
Put together a complete system with 3d print and all equipment. | Jayden | Yes

Plans for next period

### 1. Put together system prototype (all parts + 3d print print) 2. Start implementing server/Wifi connection between all different modules 3. Backend coding for camera and database searches 4. Meet with the school 5. Complete Pi software, begin networking

Task assignment per team member (to be completed before the next meeting)

Task description | Assigned to
Start implementing Zigbee connections between all modules | Jake
Coding server to camera connection | Haya
Coding server to database connections | Sara
Have complete camera functionality (QR code + License) | Jack
Get final housing design printed and put together | Jayden

Weekly Report Form. CSCE 483 Computer System Design

Project management status

### 1. Our project is running on time according to our Monday board

2.
3.

Minutes from previous meeting
-make housing model as small as possible -

Weekly Report Form. CSCE 483 Computer System Design

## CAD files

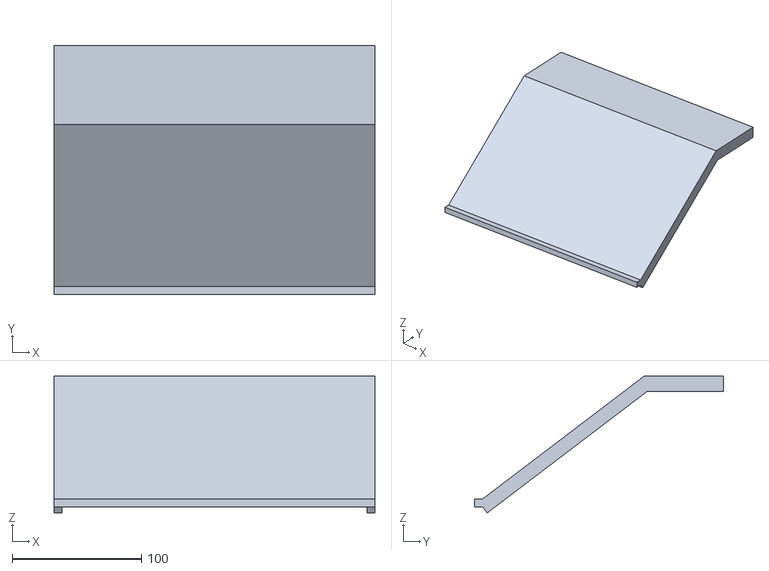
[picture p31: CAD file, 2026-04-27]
Designs/CAD Designs/Lid.stl
248.0 x 192.0 x 105.8

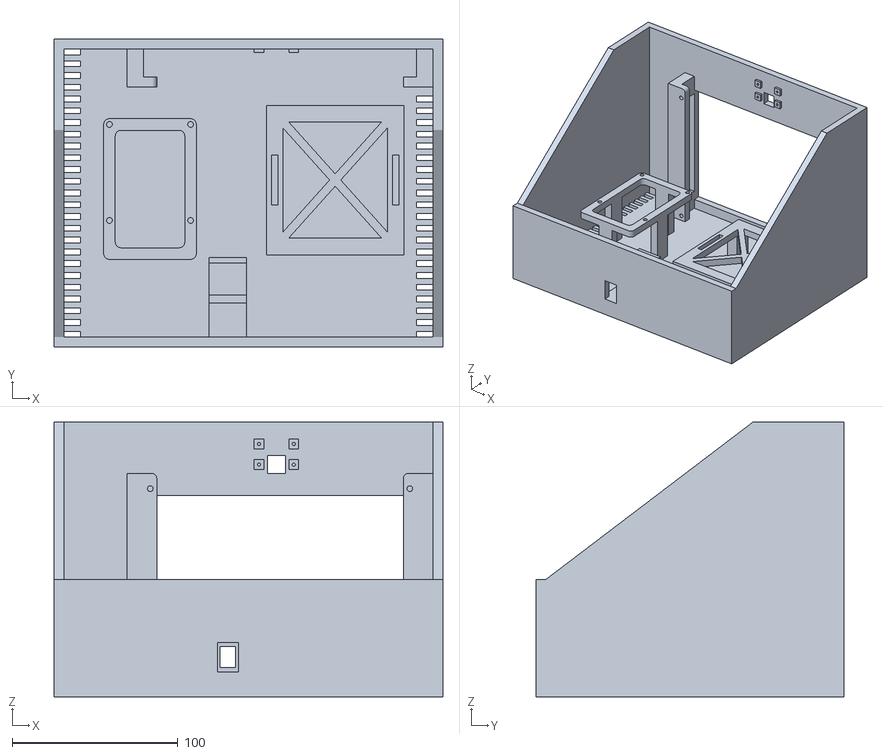
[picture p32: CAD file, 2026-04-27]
Designs/CAD Designs/Housing.stl
235.0 x 186.0 x 166.0

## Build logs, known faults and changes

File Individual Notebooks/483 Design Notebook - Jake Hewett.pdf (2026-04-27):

Design Notebook

Wednesday 1/21
- Everyone present
- Finalized student pick up system project idea with Professor
- Discussed our options for the system including facial recognition, license plate, QR scanner, and pin input.
- Identified potential issues like wireless connections, database design, and potential layout for the system. We will need to go to the school and view their current system to start designing the final layout.
Wednesday 1/28
- Haya was at the career fair, but everyone else was here.
- Wrote questions to ask people involved in the pickup process (teachers and parents).
- Wrote needs and objective statements to be finalized next Wednesday.
- The professor will plan a meeting with elementary school staff next week to discuss issues with the current system and requirements for implementation. Monday 2/2
- Everyone present
- Near finalized needs and objective statements
- A meeting with school will need to happen before statements, but we are not sure when that will happen.
- Started work on our requirements for the project. We have marketing and engineering requirements, but need justification for each requirement.
- Our group did more research on hardware components, but without a meeting, it is hard to finalize anything.

Wednesday 2/4
- Everyone present
- Needs and objective statements were looked at by the professor and TA, revised based on the feedback they gave, then finalized and turned in.
- We wrote the justifications for all the engineering and marketing requirements based on the components and design choices we have made so far.
- The constraints and standards based on the environment that we are in were also written. We will likely get those and the requirements finalized next Monday.
- With the proposal being due next Friday, we split up the work that needs to be done between us so that we can work on it without needing to be in a meeting. Monday 2/9
- Everyone present
- We had the professor go over our requirements for our project and adjusted the requirements based on his feedback.
- Most of the time today was spent working on our individual parts for the proposal document and presentation.
- We finished the meeting by doing some preparations for our presentation on Wednesday, assigning slides to each team member.
- Jack also went with the TA to look for hardware that we can use for our project

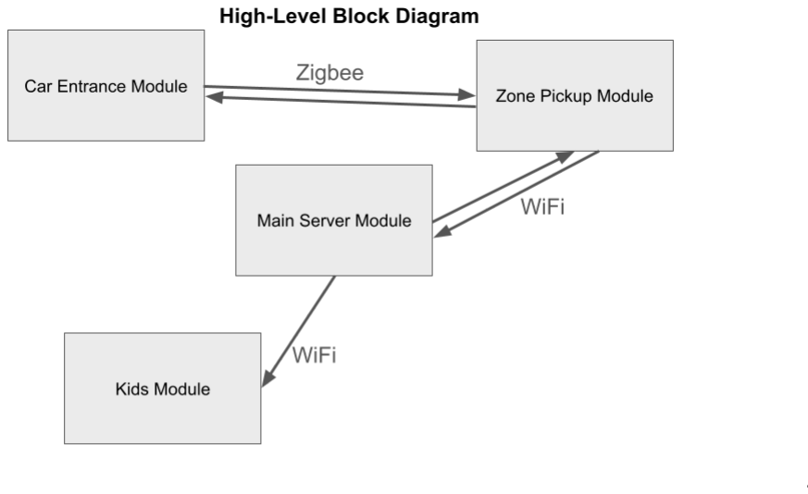
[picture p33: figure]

Wednesday 2/11
- Everyone present
- We did our proposal presentation today and received feedback on what to improve
- We watched the other groups present their projects
- We revised our presentation slides based on the feedback and resubmitted our slides
Monday 2/16
- Everyone present
- We setup our methods of communication (Github, Discord, Drive)
- We went over our proposal presentation with the professor and modified our design based on his feedback.
- We started ordering parts after getting approval from the professor. Currently, we have only ordered parts that we know we will need soon.
- We began designing the website we will use for our project, going over what information we need from parents and students, modifying our database as well.

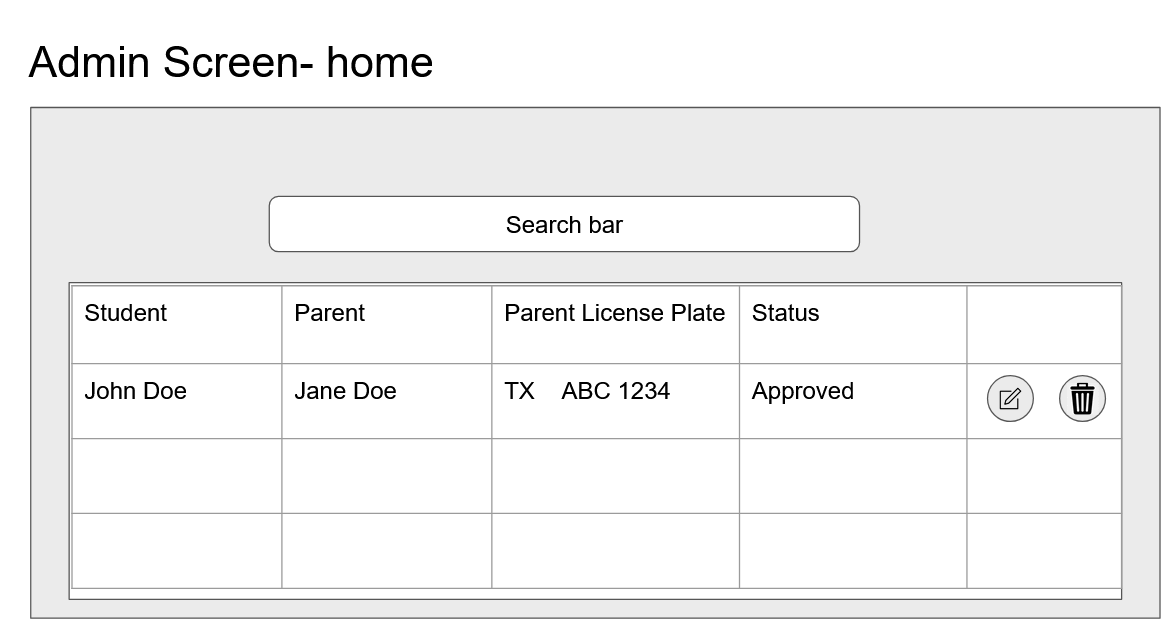
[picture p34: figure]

Wednesday 2/18
- Everyone present
- Website wireframes and initial layouts were finalized. We also selected the colors that will be used for our website.
- We started testing the camera that will be used to recognize either the license plate or a QR code, we are discussing both options
- Setup a new way to track project progress as our free trial ran out on the site we were using.
- We also set up a project on a website that will allow us to design the mount for the camera, display and the Raspberry Pi.
Monday 2/23
- Everyone present
- We had a short meeting with the professor, however we did not have much to go over with him yet as not much of the project has been completed or difficult either.
- We worked on the actual coding part for the website frontend using placeholder data and tables as the database is not yet connected to the database.
- Jack got the camera working again and we will begin testing the camera on Wednesday.

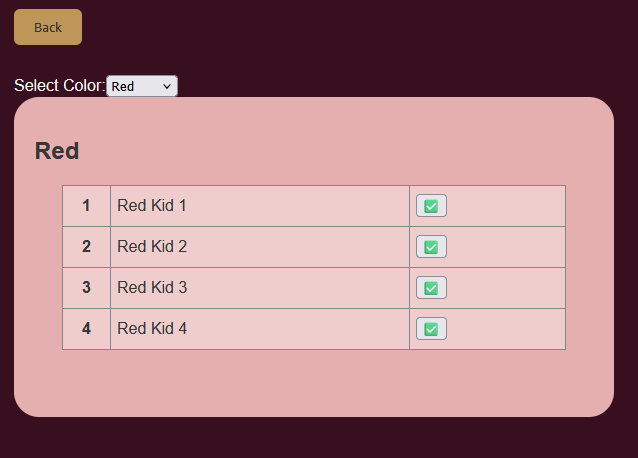
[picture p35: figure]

Wednesday 2/25
- Everyone present
- Further worked on the frontend of the website.
- Started getting Zigbee setup.
- Discussed our further project options

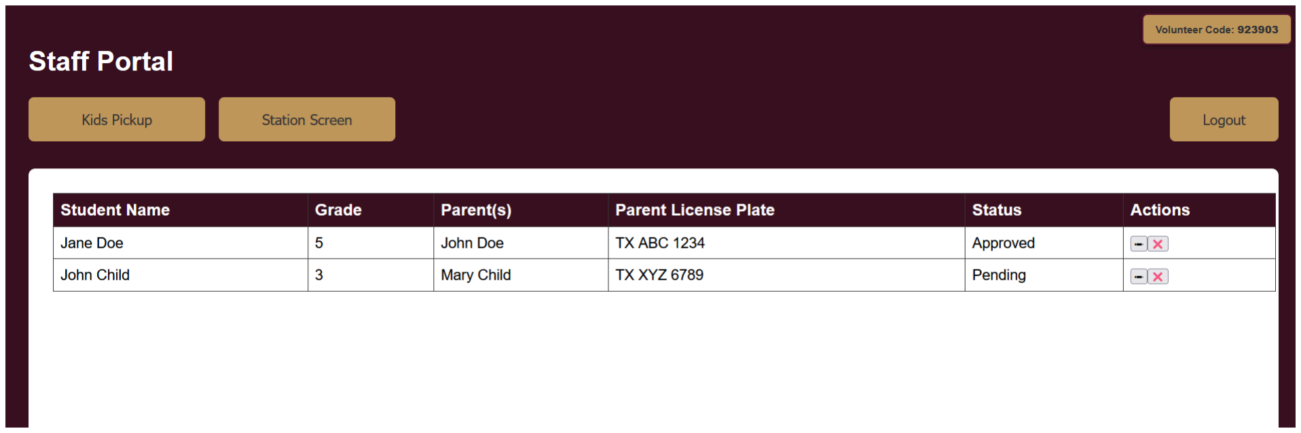
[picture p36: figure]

Monday 3/2
- Everyone present
- Haya, Sara and I worked on the backend for our website.
- Jack started testing image recognition software for the license/QR recognition.
- The meeting with the professor was very short as we have a lot of things to build and work on and we have not run into any roadblocks.

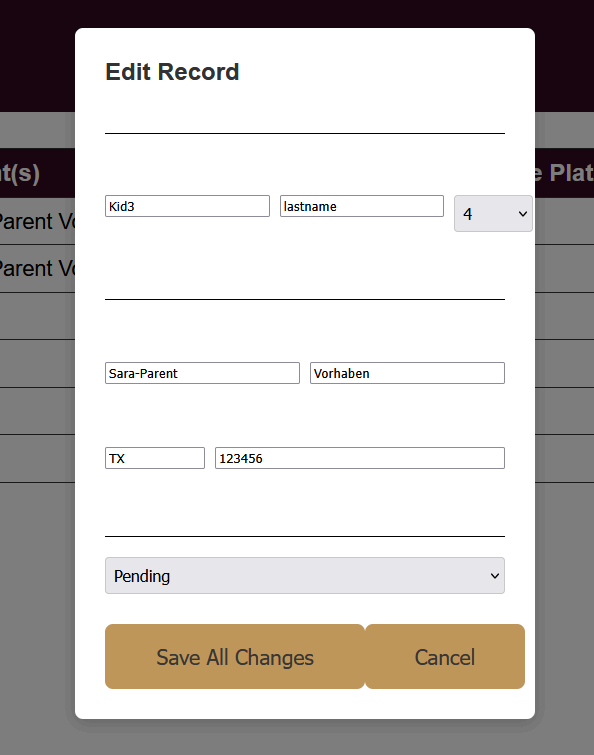
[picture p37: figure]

Wednesday 3/4
- Everyone present
- Really just a workday. Nothing new needed to be added to the plan during the meeting on Monday
- Haya, Sara and I continued to work on the backend related features for the website.
- Jack continued testing methods to better recognize license plates and Jayden continued to work on the physical and hardware parts of the project.
Monday 3/16
- Everyone present
- I worked on the CDR report
- Sara started working on QR code APIs and how to implement that.
- Met with the professor about our presentation.
Wednesday 3/18
- Remote workday
- Worked on an efficiency algorithm to optimize the car rider line system. Monday 3/23
- Everyone present
- We met for our weekly meeting with the professor.
- He suggested that we meet with a teacher from an elementary school who is involved in the pickup process to get further insight on how the process works.
- We started working on getting the server for our project setup while Jack continued working on the license plate recognition
Wednesday 3/25
- Remote workday
Monday 3/30
- Everyone present
- We met with the professor and we went over changes to the website and discussed possible design changes for the housing that the Raspberry Pi and screen will sit in.

- I worked on getting the delete feature working and deletes the child from the database
Wednesday 4/1
- Everyone present
- We had a call with someone from the elementary school who is directly involved with the car rider system at the school who provided some more specific insight into the system
- I continued working on the delete function
Monday 4/6
- Everyone present
- Had our weekly meeting with professor, but nothing really important needed to be gone over
- I finished the delete function
- Jack is continuing to work on license plate recognition
- Jayden finished the housing re-design
- Sara and Haya have been working on the server and trying to get it communicating
Wednesday 4/8
- Everyone present
- Individual workday, but we still met to see if the server was working
- We were able to get the server working and connected to the website
Monday 4/13
- Everyone present
- We had our weekly meeting with the professor, but nothing really needed to be gone over as we are just working.
- I implemented the database queries using the data from the qr code Wednesday 4/15
- Everyone present
- I wrote a script to constantly take and process pictures for our qr code reader
- We were able to get the server to communicate with the Pi and the data being sent can be processed by the server and the correct outputs are displayed.

Wednesday 4/22
- Everyone present
- We demoed our project for the professor and he liked what we have, but recommended some minor changes/improvements.

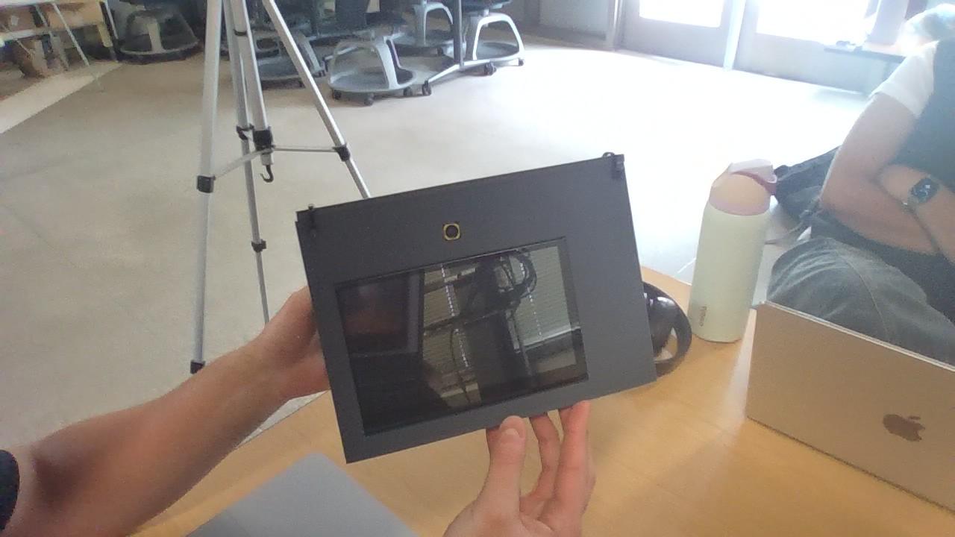
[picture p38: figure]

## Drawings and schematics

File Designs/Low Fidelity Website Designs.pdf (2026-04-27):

# Home Screen

Parent/Guardian Login | Staff Login

Create New Account

Volunteer Login

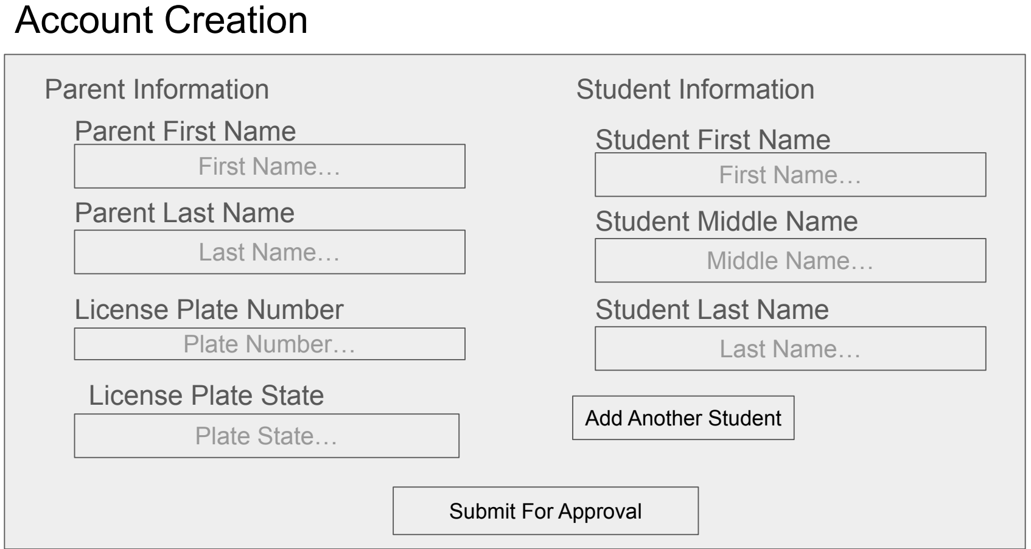
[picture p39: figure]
Account Creation; First Name…; Last Name…; Plate Number…; Plate State…; Parent First Name; Parent Last Name; Parent Information; License Plate Number; License Plate State; Student Information; Middle Name…; Student First Name; Student Middle Name; Student Last Name; Add Another Student; Submit For Approval

# Parent Portal

## Add New Child

Student First Name

Student Last Name

Student Middle Name

Submit for School
Approval
Child’s name | Pickup Status | Approved Licence Plate
Kid 1 | Approved Pick up | TX ABCDE
Kid 2 | Pending School Approval | TX ABCDE

## Parent Name’s Students

Update License
Plate | Add New Child
Once a parent | Logout

Get QR Code

# Admin Screen- home

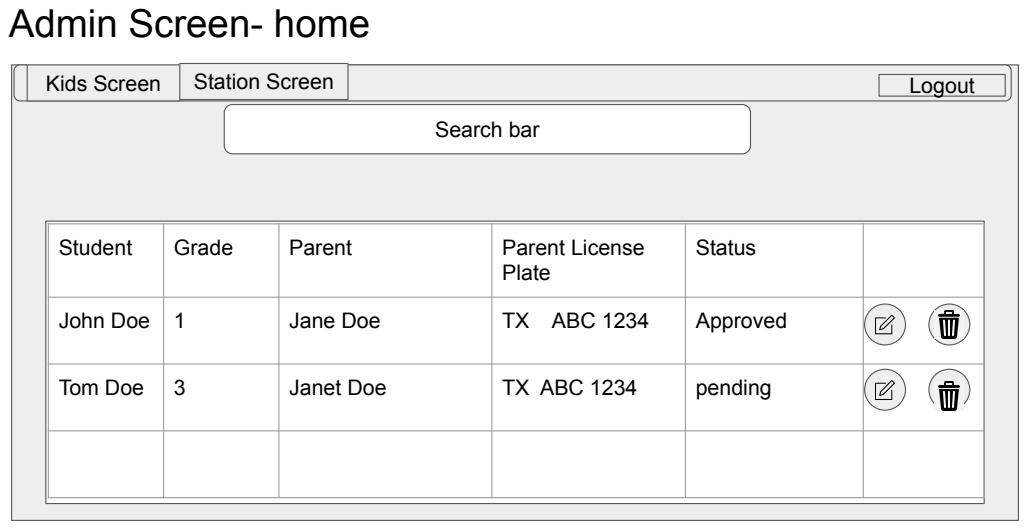
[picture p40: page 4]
Search bar; Kids Screen; Station Screen; Logout

Student | Grade | Parent | Parent License Plate | Status

John Doe | 1 | Jane Doe | TX ABC 1234 | Approved

Tom Doe | 3 | Janet Doe | TX ABC 1234 | pending

# Kids Module Screen

## Up NEXT:

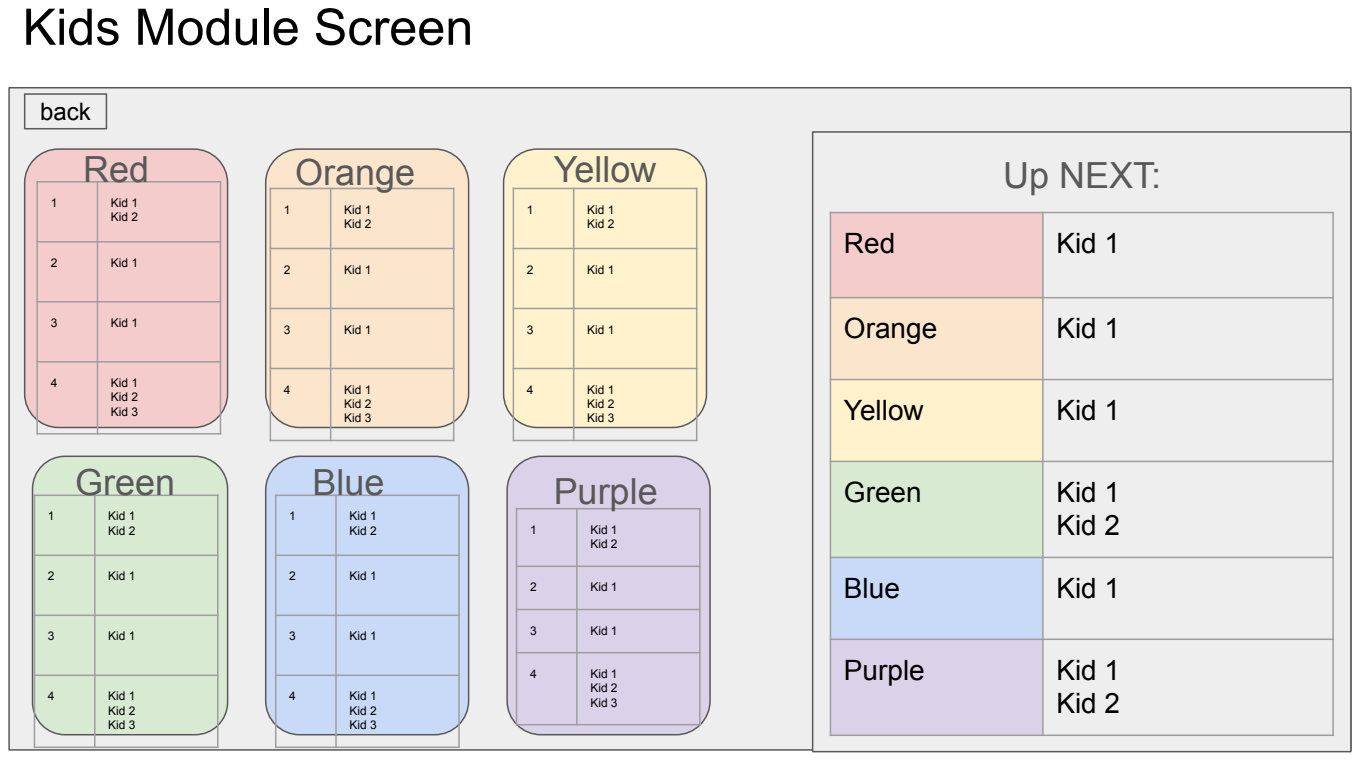
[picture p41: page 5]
Orange; Kid 1; Blue; Purple; Kid 2; Kid 2 Kid 3; Red; Yellow; Green; back

1 | Kid 1 Kid 2

Red | Kid 1

2 | Kid 1

Yellow | Kid 1

Green | Kid 1 Kid 2

3 | Kid 1

4 | Kid 1 Kid 2 Kid 3

# Pick up Screen @ Each Station

## Clicking the checkmark will mark

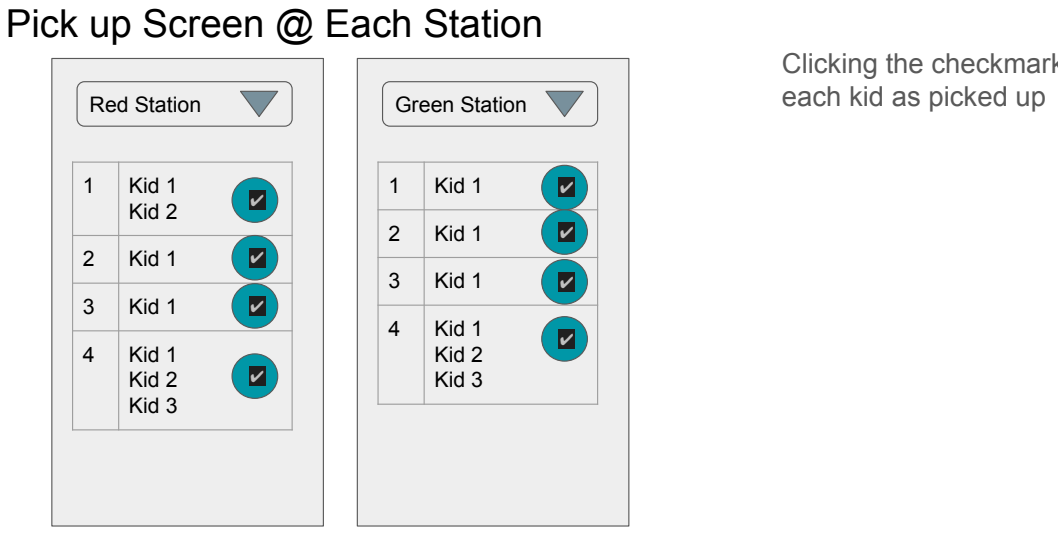
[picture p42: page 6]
Red Station; Kid 1; Kid 2; Green Station

each kid as picked up

2 | Kid 1 ✔

2 | ✔ Kid 1

3 | Kid 1 ✔

4 | Kid 1 ✔ Kid 2 Kid 3

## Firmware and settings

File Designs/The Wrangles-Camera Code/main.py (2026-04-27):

from functions import *


if __name__ == '__main__':


  """
  OEM Parameters
  0 - Legacy
  1 - LSTM Only
  2 - Combined Legacy & LSTM
  3 - Default
  """


  """
  PSM Parameters
  0 - Orientation and scrpt detection only
  1 - Automatic page segmentation with OCR
  2 - Automatic ppage segmentation without OCR
  3 - Fully automatic page segmentation (defualt)
  4 - Assume single clumn of text
  5 - Assume single vertical block of text
  6 - Assume single unimform block of text
  7 - Treat image as a single line of text
  8 - Treat image as a single word
  9 - Treat image as a single word in a circle
  10 - Treat image as a single character
  11 - Sparse text detection
  12 - Sparse text with orientation detection
  13 - raw line (no layout analysis)
  """


  # Parameters


  """
  subprocess.Popen([
    "chromium",
    "--kiosk",
    "--noerrdialogs",
    "--disable-infobars",
    "--disable-session-crashed-bubble",
    "https://thewranglers.onrender.com/display"
  ])
  """
 
  picam2 = Picamera2()
  picam2.configure(picam2.create_preview_configuration())
  size = picam2.camera_properties['PixelArraySize']
  width, height = size
  hLow, hHigh, wLow, wHigh = GetCropDim(height, width, 3)
  picam2.set_controls({
    "ScalerCrop": (wLow, hLow, wHigh-wLow, hHigh-hLow),
    "Brightness": 0,
    "Contrast": 2.0,
  })
  picam2.start()


  detector = cv2.QRCodeDetector()


  config = ('-l eng --oem 3 --psm 7 -c tessedit_char_whitelist=ABCDEFGHIJKLMNOPQRSTUVWXYZ0123456789')
  prev = ""
  while True:
    time.sleep(0.1)
    img = picam2.capture_array()
    qrStart = time.perf_counter()
    data, points, _ = detector.detectAndDecode(img)
    """
    if points is not None:
      if len(points[0]) == 4:
        print("DETECTED")
        # get low and high points for bbox
        wLow = points[0][0][0]
        hLow = points[0][0][1]
        wHigh = points[0][0][0]
        hHigh = points[0][0][1]
        for p in points[0]:
          if p[0] < wLow:
            wLow = p[0]
          if p[0] > wHigh:
            wHigh = p[0]
          if p[1] < hLow:
            hLow = p[1]
          if p[1] > hHigh:
            hHigh = p[1]


        for h in range(int(hLow), int(hHigh)+1):
          for w in range(int(wLow), int(wHigh)+1):
            ma = max(img[h][w][0], img[h][w][1], img[h][w][2])
            mi = min(img[h][w][0], img[h][w][1], img[h][w][2])
            if ma-mi < 10:
              img[h][w] = (0, 0, 0, 255)
            else:
              img[h][w] = (255, 255, 255, 255)
        data, points, _ = detector.detectAndDecode(img)
    """
    cv2.imwrite("plate.jpg", img)
    if data:
      print("QR code discovered in "+str(round(time.perf_counter()-qrStart, 2))+" seconds")
      print("QR Data:", data)
      if prev != data:
        SendPlate(data)
        prev = data
      continue
    print("No QR code discovered in "+str(round(time.perf_counter()-qrStart, 2))+" seconds")
    continue
    print("Running license plate discovery...")
    # make ultra contrast image to help license plate recognition
    preStart = time.perf_counter()
    cropped = PreProcess(img, height, width, 3)
    print("Pre-processing complete in "+str(round(time.perf_counter()-preStart, 2))+" seconds")


    dataStart = time.perf_counter()
    data = pytesseract.image_to_data(cropped, config=config, output_type = pytesseract.Output.DICT)


    img_rgb = cv2.cvtColor(img, cv2.COLOR_BGR2RGB)


    print("Data processing done in "+str(round(time.perf_counter()-dataStart, 2))+" seconds")


    SendPlate()
